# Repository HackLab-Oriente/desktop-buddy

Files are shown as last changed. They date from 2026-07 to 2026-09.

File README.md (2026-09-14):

# Desktop Buddy

Un compañero de escritorio abierto y hackeable sobre ESP32 — hecho por y para
nuestro HackLab.

## Qué es

Una criatura pequeña que vive en tu escritorio. Tiene cara, reacciona cuando
la tocas, emite sonidos y gestos, y tiene personalidad — impulsada por un LLM.
Es un **compañero primero**: la gracia, la expresividad y la personalidad son
el producto. La utilidad (recordatorios, calendario, integraciones) llega
después, como *skills* opcionales que cualquiera de la comunidad puede
construir.

Dos compromisos de diseño lo definen todo:

1. **El comportamiento es datos, no firmware.** El ESP32 ejecuta un núcleo C++
   estable (el framework). Todo lo que hace que un buddy sea *tu* buddy — su
   cara, sus estados de ánimo, sus reacciones, su voz, su system prompt — es un
   **pack de personalidad**: scripts y assets que editas desde una web y
   recargas en caliente sin recompilar. Las personalidades se comparten, se
   forkean y se intercambian — como cartuchos.

2. **Primero el dispositivo, el hub es opcional.** El buddy está completamente
   vivo por sí solo: los reflejos locales funcionan sin internet, y habla con
   un proveedor de LLM directamente por WiFi para conversar. El dispositivo
   habla con "un cerebro" a través de un protocolo pequeño — por defecto ese
   cerebro es un adaptador cloud en el propio dispositivo, pero el mismo
   endpoint puede apuntar a un servidor hub opcional para los trucos pesados
   (webhooks, integraciones, memoria a largo plazo). Sin hub no pasa nada: el
   buddy degrada con gracia, **nunca se rompe**.

## Conceptos

Dentro del framework todo es un evento en un bus, y hay cuatro primitivas de
extensión:

| Primitiva | Qué es | Ejemplos |
|---|---|---|
| **Senses** | Entradas que emiten eventos | tacto, micro, sensores, timers |
| **Expressions** | Salidas que consumen acciones | cara, sonidos, LEDs, motores |
| **Reflexes** | Comportamiento local scriptado (evento → acción), sin latencia, offline | lo acaricias → ronronea; sala a oscuras → se duerme |
| **Skills** | Capacidades mediadas por el LLM expuestas como herramientas | recordatorios, calendario (las construye la comunidad) |

Un **pack de personalidad** agrupa: system prompt, expresiones con nombre
(estado → cara/color/animación), reflejos y frases. El contrato completo está
en [docs/pack-format.md](docs/pack-format.md).

## Arranque en 5 minutos

Necesitas [ESP-IDF v6.x](https://docs.espressif.com/projects/esp-idf/en/latest/esp32/get-started/)
(la v5 **no** sirve para este proyecto) y una placa **ESP32-S3** — la N16R8 es
la de referencia. La caché de la cara y el modelo local viven en PSRAM, así
que se recomienda con firmeza. Aun sin ella el firmware arranca y dibuja, pero
la cara va a 12-25 fps en vez de 35 y el modelo local no cabe.

```bash
# --recursive importa: sin los submódulos (Berry y LovyanGFX) no compila
git clone --recursive git@github.com:HackLab-Oriente/desktop-buddy.git
cd desktop-buddy/firmware

idf.py set-target esp32s3
idf.py menuconfig           # menú "Buddy Zero": WiFi, API key (opcional)
idf.py build flash monitor
```

Guía completa, cableado y la escalera de PoCs: [firmware/README.md](firmware/README.md).

## Preparar el editor

Todo compila desde la terminal con `idf.py` — el editor es comodidad, no
requisito. Pero con el IDE bien puesto tienes autocompletado real sobre
ESP-IDF, y un botón de flash/monitor.

### VS Code, Cursor, Antigravity, Windsurf (todos son forks de VS Code)

Abre `desktop-buddy.code-workspace` y acepta las extensiones recomendadas, o
instálalas a mano:

| Extensión | ID | Para qué |
|---|---|---|
| **ESP-IDF** | `espressif.esp-idf-extension` | Build, flash, monitor, menuconfig y depuración desde el editor. Su asistente instala también el toolchain si aún no lo tienes. |
| **clangd** | `llvm-vs-code-extensions.vscode-clangd` | Autocompletado, ir-a-definición y errores en vivo, leyendo el `compile_commands.json` real del build. |
| *(opcional)* Berry | `skiars.berry` | Resaltado de los reflejos `.be`. Si no la instalas, el repo los muestra como Python, que se parece bastante. |

**No instales `ms-vscode.cpptools`** (la extensión C/C++ de Microsoft). Pelea
con clangd por las mismas funciones y da resultados peores en proyectos
ESP-IDF; además es propietaria y no está en Open VSX, así que en Cursor,
Antigravity o Windsurf directamente no se instala. El workspace la marca como
no recomendada por eso.

Dos detalles que ahorran una tarde:

- **Abre el workspace, no la carpeta suelta.** clangd necesita el
  `compile_commands.json`, que lo genera el build en `firmware/build/` — no
  en la raíz del repo. Apuntado a un sitio sin él, clangd *no falla*: adivina
  los flags y parece que funciona hasta que discrepa del compilador.
- **Compila una vez antes de esperar autocompletado.** Sin build no hay
  `compile_commands.json` que leer.

Los ajustes propios de cada máquina (ruta de ESP-IDF, puerto serie, binario
de clangd) **no van en el repo**: la extensión de ESP-IDF reescribe
`settings.json` con rutas absolutas de quien la ejecutó, así que esos
archivos están en `.gitignore`. Copia las plantillas:

```bash
cp .vscode/settings.example.json .vscode/settings.json
cp firmware/.vscode/settings.example.json firmware/.vscode/settings.json
```

### CLion (alternativa)

Funciona bien y a algunos les resulta más cómodo para C++. El proyecto es
CMake normal, así que se abre directamente — pero hay que darle el toolchain
de ESP-IDF, no el del sistema:

1. Abre la carpeta **`firmware/`** (no la raíz del repo): ahí está el
   `CMakeLists.txt` de nivel superior.
2. *Settings → Build, Execution, Deployment → Toolchains* → añade uno con el
   compilador del toolchain de Xtensa
   (`~/.espressif/tools/xtensa-esp-elf/…/bin/xtensa-esp32s3-elf-gcc`).
3. En *CMake profiles*, añade a las opciones:
   `-DCMAKE_TOOLCHAIN_FILE=$IDF_PATH/tools/cmake/toolchain-esp32s3.cmake
   -DTARGET=esp32s3`, y
   arranca CLion desde una terminal donde hayas hecho `source` del script de
   activación de ESP-IDF, para que herede `IDF_PATH`.
4. Flash y monitor siguen siendo `idf.py -p PUERTO flash monitor` en la
   terminal integrada — el plugin oficial de Espressif es solo para VS Code.

La ganancia real de CLion aquí es el indexador y el depurador; el ciclo de
flasheo se queda en la terminal en cualquier caso.

### Solo terminal

Perfectamente válido, y es como se hicieron todas las mediciones de este
repo:

```bash
source ~/.espressif/tools/activate_idf_v6.1.sh
cd firmware && idf.py build flash monitor
```

### ¿Qué placa necesito?

Un **ESP32-S3 con PSRAM**; la referencia es la N16R8 (16 MB de flash, 8 MB de
PSRAM). El ESP32 clásico estuvo soportado y funcionaba —la cara se dibujaba
por bandas a 14,4 fps— pero se retiró: sin PSRAM no hay caché de ojos ni
modelo local, y mantener dos caminos de render costaba más de lo que daba.

## ¿Dónde me meto?

Según el equipo en el que estés (o quieras estar):

- **Firmware y arquitectura** → [firmware/README.md](firmware/README.md) y
  [docs/event-registry.md](docs/event-registry.md) — el contrato entre equipos.
- **Web UI / PWA** → el servidor vive en `firmware/components/webui/`; el
  esquema de configuración, el manejo de secretos y el aprovisionamiento por
  SoftAP están propuestos en [docs/config-api.md](docs/config-api.md) — léelo
  antes de empezar.
- **Voz** → [docs/services.md](docs/services.md) y los eventos `voice.*` que
  aún no existen ([docs/event-registry.md](docs/event-registry.md), sección
  «Eventos propuestos»).
- **Electrónica** → [docs/hardware.md](docs/hardware.md) (BOM y pedidos) y
  [hardware/](hardware/) (guías de cableado por placa).
- **CAD y carcasa** → [docs/hardware.md](docs/hardware.md), sección de
  alimentación y montaje.
- **Personalidad y contenido** → [docs/pack-format.md](docs/pack-format.md) y
  [packs/](packs/) — no hace falta saber programar para escribir frases.

## Estructura del repo

```
firmware/     núcleo ESP-IDF (C++): drivers, bus de eventos, VM Berry, web
packs/        packs de personalidad (scripts + assets); packs/zero es la semilla
hardware/     guías de cableado por placa, diagramas, máscaras imprimibles
docs/         arquitectura, decisiones, talleres — índice en docs/README.md
spikes/       experimentos desechables; solo sus conclusiones van a main
```

## Documentación

### 📖 **[hacklaboriente.org/desktop-buddy](https://hacklaboriente.org/desktop-buddy/)**

Ahí está todo, con los documentos interactivos funcionando de verdad: la
reunión de equipos, el registro de eventos, el explorador de parámetros, el
laboratorio de cadenas de Markov y las dos arquitecturas.

Si solo vas a leer tres cosas: [la arquitectura](docs/architecture.md), [el
plan de talleres](docs/workshops.md) y [cómo contribuir](CONTRIBUTING.md).

> **Ojo:** los `.html` de `docs/` son páginas interactivas. Si los abres desde
> el navegador de archivos de GitHub verás el código fuente, no la página —
> usa el enlace de arriba. El índice en texto plano está en
> [docs/README.md](docs/README.md).

> Idiomas: la documentación está en español; el código y sus comentarios, en
> inglés. `CLAUDE.md` y `.kiro/` son configuración de las herramientas de IA
> del proyecto y permanecen en inglés.

## Estado

En construcción activa durante los talleres (4 sesiones, del 29 de agosto al
19 de septiembre de 2026 — ver [docs/workshops.md](docs/workshops.md)). Todo
lo que hay aquí es una propuesta — discútela. Licencia: [MIT](LICENSE).

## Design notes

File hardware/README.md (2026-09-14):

# Hardware — guías de cableado

La BOM completa, los pedidos y la arquitectura de alimentación viven en
[../docs/hardware.md](../docs/hardware.md). Aquí están las guías prácticas
por placa:

| Guía | Placa | Estado |
|---|---|---|
| [buddy-s3-display.md](buddy-s3-display.md) | **ESP32-S3 N16R8** — la de referencia | verificada en hardware |
| [buddy-zero-wiring.md](buddy-zero-wiring.md) | **ESP32 clásico** DevKit V1 | **histórica** — target retirado |
| [buddy-s3-audio.md](buddy-s3-audio.md) | **S3** — micro, ampli y tarjeta SD | **propuesta, sin firmware todavía** |

También: la máscara imprimible [`round-mask/`](round-mask/).

**Históricas**, se conservan porque documentan trabajo hecho y verificado:
[`oled-mask/`](oled-mask/), la máscara de la PoC monocroma cuyo backend ya no
existe; y el cableado del ESP32 clásico —`buddy-zero-wiring.md` más su
`buddy-zero.wireviz.yml`—, para un target que el firmware ya no compila.

Regla que lo explica casi todo: **cada chip tiene minas distintas**, y por eso
los pines viven en `menuconfig` y nunca hardcodeados. En el S3 —el único
target— GPIO 33–37 son la PSRAM, 19/20 el USB, 26–32 la flash y 0/3/45/46
strapping. En el clásico eran 6–11 flash, 12 y 15 strapping y 34–39 solo
entrada: eso ya solo hace falta para leer el cableado histórico.

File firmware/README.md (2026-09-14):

# Firmware — Buddy Zero

El núcleo del framework: bus de eventos, host de Berry, drivers de Senses y
Expressions, el adaptador de cerebro cloud y la web de recarga en caliente.

## Un target

| | `esp32s3` (referencia) |
|---|---|
| Bus, Berry, web UI, cerebro cloud, tacto, NFC | ✓ |
| Cara GC9A01 a color | ✓ frame completo + caché PSRAM, **33 fps medidos** |
| Modelo local / voz | ✓ / planificado |
| Verificado | en hardware, completo |

## La capa gráfica

Los ojos los dibuja **nuestro** renderer de campos de distancia (SDF), porque
la ceja y el guiño de felicidad se recortan de la forma como *cobertura* —
ninguna primitiva de librería expresa eso. Todo lo demás (driver del panel,
sprites, blitting) es **LovyanGFX**.

**La fuente también es nuestra**, y no por gusto: *todas* las que trae
LovyanGFX se paran en 0x7E/0x7F — `Font2` calcula literalmente
`(uniCode - 0x20) < 0x60`, 96 glifos. Es decir, `á` salía como un cuadrado.
Las únicas fuentes Unicode de la librería son las efont, y son 17–32 MB de
CJK. Así que `tools/make_font.py` genera `font_latin.h` (DejaVu Sans 13 px,
0x20–0xFF, **4 KB**) y con eso el buddy escribe español de verdad. Se
regenera a mano y se commitea; el build no lo ejecuta.

Lo que va más allá de 0x00FF —las comillas curvas y las rayas que un LLM
adora— lo pliega `latin1.h` a ASCII antes de dibujar, porque un glifo que no
existe se dibuja como nada y `don’t` perdería el apóstrofo.

En el S3 los ojos van **cacheados**: el SDF cuesta 40–100 ms por frame, pero
la imagen solo cambia al parpadear o cambiar de emoción — una sacada es una
*traslación* de una imagen que no cambió. Renderizar una vez por (emoción,
apertura) en tres sprites PSRAM y blitear con offset de mirada lo lleva de 13
a 33 fps medidos, píxel por píxel idéntico. Todo se midió primero en
[../spikes/lovyangfx-gc9a01/](../spikes/lovyangfx-gc9a01/README.md), que
registra las trampas — la principal: **LovyanGFX guarda los sprites de 16 bpp
en big-endian**; escribir little-endian nativo en `getBuffer()` convierte los
degradados en franjas arcoíris.

## El arranque

`face_start()` corre primero en `app_main`, así el splash está en pantalla
mientras lo lento pasa por detrás. La retroiluminación no se enciende hasta
después del init del panel — el arranque se lee como oscuro → estática → logo.
El logo del HackLab «sintoniza» como una tele estropeada (~1,6 s) y la línea
de estado la publican los pasos reales de `app_main` vía `boot.status`.
`boot.ready` hace glitch del splash a la cara. En un arranque típico la línea
se queda ~4 s en "connecting wifi": ese es el cuello de botella honesto.

## Setup

```bash
# 1. ESP-IDF v6.x (la v5 NO está soportada). El instalador EIM deja el script
#    de activación en ~/.espressif/tools/activate_idf_v6.1.sh — haz source.
# 2. Submódulos: Berry (VM de reflejos) y LovyanGFX (capa gráfica).
git submodule update --init
cd firmware/components/berry_host/berry
mkdir -p generate && python3 tools/coc/coc -o generate src default -c default/berry_conf.h
#    (Sin el submódulo/codegen el build compila igual, pero el buddy se queda
#     sin reflejos: el fallback en C se borró en #71 por ser una segunda copia
#     del comportamiento semilla que se desincronizaba en silencio.)

cd ../../..            # de vuelta a firmware/
idf.py set-target esp32s3    # el único target
idf.py menuconfig            # menú "Buddy Zero": WiFi, API key, pines
idf.py build flash monitor
```

`set-target` regenera `sdkconfig` desde `sdkconfig.defaults` +
`sdkconfig.defaults.esp32s3`, con la tabla de particiones de 16 MB e imagen
de modelo local.

### Build de desarrollo

`CONFIG_BUDDY_DEBUG` viene en `n`, así que un `monitor` recién clonado sale
callado: no traza los eventos del bus, ni los cuerpos HTTP del cerebro, ni las
lecturas del táctil. Está en `n` por una razón medida —el tracer bloquea el bus
15-20 ms por gesto a 115200 baudios— que solo importa en un buddy terminado.
Mientras desarrollas, pide `sdkconfig.defaults.dev`:

```bash
idf.py -DSDKCONFIG_DEFAULTS="sdkconfig.defaults;sdkconfig.defaults.esp32s3;sdkconfig.defaults.dev" set-target esp32s3
```

Los ficheros van explícitos a propósito: `-DSDKCONFIG_DEFAULTS` sustituye la
lista entera, y olvidar el del target deja el S3 sin PSRAM y por tanto sin
caché de ojos. El fichero es tuyo para crecer: lo que quieras en tu mesa y no
en el buddy de nadie más.

### Tus credenciales, y por qué no van en `sdkconfig`

`idf.py set-target` **regenera `sdkconfig` desde cero**, así que todo lo que
solo viviera ahí —tu SSID, tu contraseña, tu clave de API— desaparece. Duele
cada vez que se cambia de target o de versión de ESP-IDF.

Copia `sdkconfig.defaults.local.example` a `sdkconfig.defaults.local`, que
está gitignorado, y añádelo **al final** de la lista, que es la posición que
gana:

```bash
idf.py -DSDKCONFIG_DEFAULTS="sdkconfig.defaults;sdkconfig.defaults.esp32s3;sdkconfig.defaults.dev;sdkconfig.defaults.local" \
       set-target esp32s3
```

Con eso, regenerar es gratis: `fullclean`, `set-target`, y sigues teniendo tu
red y tu clave.

Que la clave de API viva en un fichero de build es una decisión de PoC, no el
diseño. En v1 va en NVS y se pone desde el web UI (#5). Mientras tanto, ten
presente que **el binario compilado es una credencial**: `strings
build/buddy.bin` la encuentra. No lo pases por un taller ni lo cuelgues de
una release.

## Cableado

Los pines viven en `menuconfig`, nunca hardcodeados.

| Periférico | ESP32-S3 |
|---|---|
| GC9A01 (SPI, **3V3**) | SCL 12 · SDA 11 · CS 10 · DC 9 · RST 8 · BL 7 |
| Almohadilla táctil | GPIO 4 |
| Anillo WS2812 (**5V**) | DIN 21 |
| RC522 (opcional, **3V3**) | SCK 39 · MISO 40 · MOSI 41 · SDA/CS 42 · RST 38 |

En el RC522 no hay ningún pin marcado «CS»: el módulo serigrafía **`SDA`**, que
en SPI es el chip select. El `IRQ` va sin conectar — el driver hace polling.

Guía paso a paso con checklist de primer arranque:
[../hardware/buddy-s3-display.md](../hardware/buddy-s3-display.md).

Minas del S3: 33–37 PSRAM octal, 19/20 USB, 26–32 flash, 0/3/45/46 strapping.

## La escalera de PoCs

1. **Latido** — flashea, mira el log serie, toca el jumper: `touch.pet` → el
   anillo respira. El bus funciona.
2. **Proto-cara** — la pantalla muestra dos ojos paramétricos: parpadeos,
   sacadas, emociones. Payloads de `face.emotion`: neutral, happy, curious,
   sleepy, surprised, angry, sad, suspicious.
3. **Cartuchos** — acerca un llavero RFID: `nfc.tag` + UID en el log. Pon tus
   UIDs en `packs/zero/reflexes/main.be` vía web y repite.
4. **Cerebro** — con WiFi + API key: acaricia el cable, el buddy pregunta a
   Claude y la emoción de la respuesta mueve la cara.
5. **Recarga en caliente** — abre `http://<ip-del-buddy>/`, edita reflejos en
   el navegador, sube — el comportamiento cambia sin reflashear. La tesis
   entera del framework en un botón.

## Estructura

```
components/bus/          bus de eventos (testeable en host — ver host_test/)
components/senses/       tacto, RC522 → eventos
components/expressions/  cara a color, anillo WS2812 ← acciones
components/brain/        contrato de cerebro: adaptador cloud (Claude)
components/webui/        WiFi STA + editor de reflejos + recarga en caliente
components/berry_host/   VM Berry, API buddy.*, despacho de eventos
main/                    arranque + el único reflejo del framework (brain.reply)
../packs/zero/           los reflejos Berry de Buddy Zero
```

El contrato de eventos completo (con dueños por prefijo y agujeros conocidos):
[../docs/event-registry.md](../docs/event-registry.md).

## Tests de host

```bash
cd host_test
c++ -std=c++17 -Wall -I../components/bus/include test_bus.cpp ../components/bus/bus.cpp -o test_bus
./test_bus    # se espera: "bus: all tests passed"

# El decodificador NDEF lee bytes de una pegatina que cualquiera puede dejar
# en tu mesa, así que se prueba con sanitizers puestos.
c++ -std=c++17 -Wall -fsanitize=address,undefined -fno-sanitize-recover=all \
  -I../components/senses test_ndef.cpp -o test_ndef
./test_ndef   # se espera: "ndef: all tests passed"

# El normalizador de texto recorre UTF-8 del LLM hacia un buffer fijo: mismo
# tipo de código, mismos sanitizers.
c++ -std=c++17 -Wall -fsanitize=address,undefined -fno-sanitize-recover=all \
  -I../components/expressions test_latin1.cpp -o test_latin1
./test_latin1 # se espera: "latin1: all tests passed"
```

## Estado

- **Verificado**: compila en ESP-IDF v6.1; el bus pasa sus tests de host; el
  S3 completo funciona en hardware (cara, anillo, tacto, WiFi, cerebro
  Claude). Render medido: **30,3 ms/frame (33,0 fps)**.
- **Sin cablear todavía**: audio (INMP441/MAX98357A), tarjeta SD, sensores
  I2C.

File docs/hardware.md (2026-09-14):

# Hardware: componentes y cableado (build de referencia v1)

Construimos desde cero: elegimos componentes, los cableamos, y diseñamos e
imprimimos nuestra propia carcasa. Esta es la BOM propuesta para v1 — la
elección final es decisión de grupo en la sesión 1, pero **los componentes
deben pedirse antes de la sesión 1**.

## Núcleo

| Pieza | Sugerencia | Notas |
|---|---|---|
| MCU | **Devkit ESP32-S3, N16R8** (16 MB flash / 8 MB PSRAM) | El S3 es necesario para el roadmap de voz (instrucciones vectoriales de ESP-SR); la PSRAM para gráficos + buffers de audio. Pilla el devkit con ambos puertos USB expuestos. *(El ESP32 clásico se retiró en #80: sin PSRAM no hay caché de ojos, ni modelo local, ni voz, y mantener el segundo camino de render costaba más de lo que devolvía.)* |
| Pantalla | **A elección de cada uno:** GC9A01 redonda 1,28″ o ST7789 cuadrada 1,54″ — ambas 240×240, SPI | Misma resolución, mismo cableado, mismo stack gráfico — solo cambia la secuencia de init (un flag, no un fork). Regla: las caras se crean en un canvas de 240×240 con ojos/boca dentro del círculo inscrito ("zona segura redonda"). Evita los OLED I2C clase SSD1306: monocromos, 128×64, e I2C demasiado lento para animación. Rectangulares más grandes (ST7789 2″ / ILI9341 2,4–2,8″, 320×240) son post-v1 — rompen la paridad de resolución. |
| Tacto (caricias) | Pines capacitivos **nativos del ESP32** + cinta de cobre bajo la carcasa | Gratis (sin componente), y "acariciar la carcasa" gana a "tocar la pantalla" para una criatura. Una pantalla táctil es extra opcional. |
| Micrófono | **INMP441** (MEMS I2S) | Digital, sin líos analógicos. v1 lo usa para nivel de sonido (un Sense) y streaming STT del push-to-talk; el uso de sobremesa no necesita array de micros. |
| Salida de audio | **MAX98357A** (ampli I2S) + altavoz 4Ω 3W (~28 mm) | Chirps, efectos y reproducción TTS para el bucle PTT de v1. Sin canal de loopback → sin AEC → half-duplex por diseño. |
| Extras | LED RGB WS2812 (luz de ánimo), un botón de repuesto | Barato, expresivo, buen material de relleno para talleres. |

Coste estimado por buddy: **≈ 20–30 €** en cantidades unitarias. Pide al menos
un repuesto de todo; los micros MEMS y las pantallas baratas tienen bajas.

## Lista de compra y seguimiento de pedidos

Marca los items al pedirlos. **Decisión del lab (2026-07): construir 2–3
prototipos, no uno por miembro** — el pedido actual cubre exactamente eso (3
builds con repuestos). Cuando v1 esté sólida, el camino a un producto pulido
es un **lote de PCB portadora fabricada** (ver Alimentación y montaje), no más
protoboards.

### Componentes de núcleo (verificados 2026-07-13, pedidos)

- [x] Devkit ESP32-S3 N16R8, doble USB-C, pack de 3 (Hosyond) — [B0F5QCK6X5](https://www.amazon.com/dp/B0F5QCK6X5)
- [x] Pantalla GC9A01 redonda 1,28″, 240×240 SPI, pack de 5 (D-FLIFE) — [B0DCBM8KV1](https://www.amazon.com/dp/B0DCBM8KV1)
- [x] Micrófono MEMS I2S INMP441, pack de 5 — [B0C1C64R8S](https://www.amazon.com/dp/B0C1C64R8S)
- [x] Breakout ampli I2S MAX98357A 3 W, pack de 6 — [B0FHWB5VFW](https://www.amazon.com/dp/B0FHWB5VFW)
- [x] Anillo WS2812 de 12 LED, pack de 5 — [B0C77WMM7B](https://www.amazon.com/dp/B0C77WMM7B)
  (capar el brillo en firmware: 12 LEDs a blanco pleno ≈ 700 mA a 5 V)
- [x] Altavoz 4Ω 3W ultrafino 35×25×6,8 mm, coleta JST 1.25, pack de 5 (DWEII) — [B0F3CY5ZD2](https://www.amazon.com/dp/B0F3CY5ZD2)
  (nota de montaje: cortar el JST a ras, pelar 5 mm, estañar, atornillar al terminal de salida del MAX98357A)

### Extras

- [ ] Kit de protoboards, 2×830 + 2×400 puntos + 126 jumpers (BOJACK) — [B08Y59P6D1](https://www.amazon.com/dp/B08Y59P6D1) — prototipado sesiones 1–3
- [ ] Cables Dupont 120 uds M-M/M-H/H-H (ELEGOO) — [B01EV70C78](https://www.amazon.com/dp/B01EV70C78) — los H-H conectan el módulo de pantalla directo a los pines del devkit
- [x] Cinta de cobre 2″×33 ft, adhesivo conductor (LOVIMAG) — [B07C6YLNYL](https://www.amazon.com/dp/B07C6YLNYL) — las almohadillas capacitivas
- [x] Pulsadores táctiles 6 mm, pack de 20, para protoboard — [B07WF76VHT](https://www.amazon.com/dp/B07WF76VHT) — entrada de repuesto / botón de boot
- [x] Protoboard soldable (ElectroCookie) — [B07ZYNWJ1S](https://www.amazon.com/dp/B07ZYNWJ1S) — el montaje final replica el layout de protoboard 1:1
- [x] Kit de insertos M3 + tornillos, 361 uds con puntas para soldador — [B0G8JLX1HR](https://www.amazon.com/dp/B0G8JLX1HR) — atornillar la carcasa; la vas a reabrir constantemente
- [x] Cable de silicona 22 AWG, 6 colores ×10 ft (Fermerry) — [B089CQHRDT](https://www.amazon.com/dp/B089CQHRDT) — almohadillas, tiradas de altavoz, piezas montadas en carcasa

### Hardware del hack port (por pedir)

El hack port del panel trasero necesita conectores de verdad, no solo un
recorte en la carcasa:

- [ ] Surtido de tiras de pines, macho + hembra, fila simple/doble 2,54 mm, 138 uds — [B0GLHJ3DXH](https://www.amazon.com/dp/B0GLHJ3DXH) (~$10) — el puerto en sí es un zócalo **hembra** 2×4 (compatible Dupont) pegado al recorte; el kit además cubre reparaciones de headers en todas partes
- [ ] Kit de cables Qwiic/Stemma QT, JST-SH 1,0 mm a Dupont — [B08HQ1VSVL](https://www.amazon.com/dp/B08HQ1VSVL) (~$8) — adapta el enorme ecosistema de sensores I2C Qwiic/Stemma directo al hack port, sin crimpar, sin conector SH de panel

**Mapa 2×4 propuesto** (congelar en la sesión 1):

```
3V3   SDA
5V    SCL
GND   GPIO A  (ADC + táctil)
GND   GPIO B  (ADC + táctil)
```

I2C es el bus de extensión (por direcciones, alimentado, y todo el catálogo
Qwiic entra con los cables adaptadores); los dos GPIO crudos cubren botones,
sensores analógicos o una almohadilla táctil extra. En firmware: los pines
del hack port son de la capa Berry — lectura/escritura digital/analógica y
tacto desde scripts con cero C++; los dispositivos I2C usan Senses con
driver.

### Sensores integrados v1 (por pedir)

Kit de consciencia, integrado en cada buddy (no son accesorios del hack
port). Todos alimentan el `sensor_snapshot` del Brain (consciencia
conversacional gratis) y emiten eventos del bus para los reflejos. Los
drivers/máquinas de estados los escriben agentes de IA; los costes humanos
son colocación, montaje y ajuste — anotados por sensor.

- [ ] Combo AHT20 + BMP280 temp/humedad/presión, I2C, pack de 5 — [B0G1RDY1Y8](https://www.amazon.com/dp/B0G1RDY1Y8) (~$8)
  — colocación: en la rejilla de entrada, bajo en la carcasa (el autocalentamiento del recinto lee 3–5 °C de más). La tendencia de presión = charla del tiempo.
- [ ] MPU6050 (GY-521) acelerómetro + giroscopio, I2C, pack de 5 (AITRIP) — [B07RXQGGJX](https://www.amazon.com/dp/B07RXQGGJX) (~$10)
  — montaje: rígido, atornillado o bien pegado a la carcasa (no flotando de los cables). La capa de gestos (`motion.pickup`, `motion.shake`, `motion.tilt`) la escribe la IA pero necesita play-testing humano para ajustar umbrales — presupuesta una hora divertida.
- [ ] Radar de presencia mmWave LD2410C, UART/GPIO, pack de 3 — [B0FKBF3CT4](https://www.amazon.com/dp/B0FKBF3CT4) ($19)
  — el rey de la consciencia: detecta que llegas/te sientas/te vas *a través de la carcasa de PLA* — cero agujeros. Montar mirando al frente tras la pared. Usa UART, no I2C.
- [ ] VL53L0X distancia ToF (láser), I2C, pack de 5 (Starry) — [B0DZWS6WC5](https://www.amazon.com/dp/B0DZWS6WC5) ($15) — *opcional*
  — anticipación: mano acercándose → emocionado antes del contacto. Necesita apertura real o ventana transparente (el láser IR no atraviesa el PLA).

~$58 en total, cubre 3 builds con repuestos. Todos los sensores I2C comparten
el único bus (un par `Wire`, direcciones distintas — sin coste de pines por
sensor). Descartados por ahora: calidad de aire clase ENS160 (necesita
rodaje, deriva — buen experimento de lab más adelante), PIR (instrumento
romo; el radar lo supera en todo).

### Alimentación, prep de servos y NFC (por pedir)

Piezas de la arquitectura de alimentación (ver *Alimentación y montaje*) más
las dos adiciones aprobadas con vistas al futuro:

- [ ] Extensión USB-C de panel, macho→hembra, montaje a tornillo, pack de 2 — [B0G43JGJRX](https://www.amazon.com/dp/B0G43JGJRX) ($10; **pedir ×2** para 3 builds + repuesto)
  — la entrada de energía de la carcasa; alimenta el raíl de 5 V directo, el USB del devkit queda solo para depurar
- [ ] Micro servos MG90S de engranaje metálico, pack de 6 — [B0DRHX1L5Q](https://www.amazon.com/dp/B0DRHX1L5Q) ($18)
  — 2 por buddy para el cuello pan/tilt de v2; el prototipado en banco puede empezar justo tras la sesión 4. v1 solo *reserva* sus pines y margen de potencia
- [ ] Módulo lector NFC PN532 (modo I2C), pack de 3 — [B0DTHPL3GG](https://www.amazon.com/dp/B0DTHPL3GG) ($19)
  — un dispositivo más en el bus I2C compartido; lee a través de la carcasa de PLA, cero agujeros. Stretch de la sesión 4: tap a un tag para cambiar de personalidad
- [x] Pegatinas NFC NTAG215, pack de 50 — [B0CHVWTRGC](https://www.amazon.com/dp/B0CHVWTRGC) ($13)
  — cartuchos de pack, tokens de modo, tótems impresos. Regla: los tags disparan solo acciones de lista blanca — nunca auth, nunca entrada cruda al Brain
- [x] Módulo micro SD, SPI 3,3 V (sin conversor de nivel), pack de 6 (WWZMDiB) — [B0BV8ZQ81F](https://www.amazon.com/dp/B0BV8ZQ81F) ($7)
  — almacenamiento de media para packs de contenido (voz pre-generada, imágenes, sonidos — ej. el explicador de juegos de mesa). Comparte el bus SPI de la pantalla con su propio CS; montado solo-lectura en operación normal, escrituras solo en subidas desde la web. Evita las variantes con "conversor lógico 3.3V/5V" — el conversor causa los fallos clásicos de SD-en-ESP32

### Confirmar que alguien ya tiene (no pedir a ciegas)

- [ ] Soldador + estaño + flux (el soldador también instala los insertos)
- [ ] Pelacables, alicates de corte a ras
- [ ] Pistola de silicona caliente
- [ ] Multímetro
- [ ] Cables USB-C **de datos** (los de solo-carga son el clásico sumidero de tiempo en talleres)
- [ ] **Cargadores de pared USB-C, 15 W+ (5 V/3 A)** — uno por buddy; cualquier cargador de móvil moderno vale
- [ ] Tarjetas micro SD, 8–32 GB (clase A1 vale) — una por buddy; hay en cualquier cajón
- [ ] Polyfuse ~500 mA (protección del hack port) + condensadores electrolíticos de 1000 µF (raíl de 5 V) — piezas clásicas de cajón de lab
- [ ] Filamento PLA/PETG para la carcasa

## Alimentación y montaje

**Regla de arquitectura: las cargas nunca pasan por el devkit.** El consumo
pico de v1 es ~1,1–1,5 A a 5 V (ráfagas WiFi + altavoz + anillo capado +
radar), que excede el conector USB y las pistas de 5 V del devkit — la fuente
clásica de fantasmas tipo "se reinicia cuando suena el altavoz".

- **Entrada de energía**: USB-C de panel en la carcasa → **raíl de
  distribución de 5 V** en la protoboard (topología en estrella) con un
  electrolítico de 1000 µF. Devkit, ampli, anillo, radar y hack port beben
  todos del raíl. El USB del devkit queda solo para programar/depurar.
- **Fuente**: cargador USB-C de 5 V/3 A (15 W+) por buddy. El margen ya cubre
  los servos de v2 (~1–1,5 A de picos de bloqueo) sin rehacer nada.
- **El 5 V del hack port** pasa por un polyfuse de ~500 mA — un accesorio en
  corto apaga el experimento, no el buddy.
- **Gobernador de potencia en firmware**: cap de brillo del LED, volumen
  máximo del altavoz y (después) los movimientos de servo se coordinan en la
  capa Expression para que los peores casos no se apilen. ~20 líneas;
  política, no conocimiento tribal.
- **La batería = el módulo "base de potencia" de v2, no la cabeza.** Una
  18650 + placa de carga/boost (clase IP5306: carga, boost a 5 V y load
  sharing en un chip) vive en la misma base atornillable que el cuello servo:
  la masa de la batería hace de lastre para la cabeza móvil, el calor queda
  lejos del sensor de temperatura, y la base alimenta la cabeza por la
  costura USB-C existente — la cabeza no distingue pared, power bank o
  batería. Hack de portabilidad v1.5: cualquier power bank USB-C (el consumo
  en reposo de ~200 mA queda por encima del umbral de autoapagado de los
  power banks baratos).
- Protoboard para las sesiones 1–2; pasar a protoboard soldada o PCB
  portadora simple para el montaje final en la sesión 4. Una PCB portadora
  diseñada en paralelo por quien le interese es un side-track estupendo pero
  no puede bloquear el montaje.

## Carcasa

- Impresa en 3D, carcasa de dos piezas alrededor de la pantalla ("cabeza")
  con rejilla de altavoz, agujero de micro y una **entrada USB-C de panel**
  (desacoplada del puerto del devkit — se acabó alinear recortes con una
  placa). Almohadillas capacitivas pegadas por dentro donde la acariciarías
  naturalmente (encima de la cabeza).
- **Base preparada para cuello**: interfaz inferior plana con torres de
  tornillo M3 y canal de cables, para que la base de potencia v2 (servos +
  batería) se atornille sin reimprimir la cabeza.
- **Zona de tap NFC**: el PN532 se monta tras la carcasa (lee a través de
  2–3 mm de PLA); imprime un pequeño icono de tap en la superficie. El radar
  igualmente ve a través de la carcasa — montarlo mirando al frente.
- El diseño de la carcasa empieza en la sesión 1 (medir componentes reales),
  primera impresión de prueba en la sesión 2, impresión final entre las
  sesiones 3 y 4.

## Presupuesto de pines (comprobación, ESP32-S3)

Pantalla SPI (5–6 pines), micro I2S (3), ampli I2S (3), almohadillas táctiles
(2–4), LED (1), botón (1), bus I2C (2 — compartido por todos los sensores
integrados *y* el hack port), UART del radar (2) — cómodamente dentro del
número de GPIO del S3, dejando de sobra GPIO libres sacados a un conector en
la carcasa (el "hack port") para sensores de miembros y actuadores futuros.
Sacar GPIO sin usar + 3V3/GND a un conector externo es parte del diseño v1 de
la carcasa a propósito: es la promesa de extensibilidad hecha física.

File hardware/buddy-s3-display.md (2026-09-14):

# El buddy en ESP32-S3 — primer arranque: la cara redonda

Meta de este paso: la pantalla redonda GC9A01 mostrando la cara a color en el
ESP32-S3 (N16R8). No hace falta cablear nada más todavía — tacto, audio y
RC522 vienen deshabilitados por defecto en esta config.

## Cableado — GC9A01 (SPI) → ESP32-S3

Coincide con los defaults del firmware en `firmware/main/Kconfig.projbuild`.
Cablea por las **etiquetas de la serigrafía de la pantalla**, no por el orden
de los pines.

| Pin GC9A01 | ESP32-S3 | Notas |
|---|---|---|
| VCC | 3V3 | nunca 5 V |
| GND | GND | |
| SCL | GPIO 12 | reloj SPI (SCLK) |
| SDA | GPIO 11 | datos SPI (MOSI) |
| RES | GPIO 8 | reset |
| DC | GPIO 9 | dato/comando |
| CS | GPIO 10 | chip select |
| BLK | GPIO 7 | retroiluminación (o a 3V3 y BL = -1) |

**Minas de pines del ESP32-S3 N16R8** (la razón de esta elección):
- **GPIO 33–37 son la PSRAM octal** — no los uses jamás.
- GPIO 19/20 son USB, 0/3/45/46 son strapping, 26–32 son la flash.
- GPIO 7–12 (los elegidos) están todos libres.

## Flashearlo

```bash
cd firmware
idf.py set-target esp32s3      # primera vez en el S3 — regenera la config
idf.py menuconfig              # Buddy Zero → WiFi + clave de Anthropic (opcional)
idf.py build flash monitor
```

El ESP32-S3 + GC9A01 es el único target. El ESP32 clásico estuvo soportado y
se retiró; su cableado se conserva como registro en
[buddy-zero-wiring.md](buddy-zero-wiring.md).

## Checklist de primer arranque (idf.py monitor)

1. `face` / `buddy zero is alive` en el log, sin abortos de
   `ESP_ERROR_CHECK`.
2. Estas dos líneas **son normales**, aunque una salga en rojo:

   ```
   E spi: spi_bus_initialize(897): SPI bus already initialized.
   W LGFX: Failed to spi_bus_initialize.
   ```

   El firmware reclama el bus SPI antes que LovyanGFX a propósito, y esas dos
   líneas son el relevo. Están explicadas en `claim_bus()`, en
   `firmware/components/expressions/lgfx_buddy.h`.
3. La pantalla redonda muestra dos ojos cian sobre negro que **parpadean y
   derivan**.
4. Si la pantalla está en negro: revisa el cableado de RES/DC/CS y el 3V3.
5. Si los colores salen invertidos o mal (ej. ojos magenta): es un clon del
   GC9A01 con otro orden — invierte `cfg.invert` y/o `cfg.rgb_order` en
   `firmware/components/expressions/lgfx_buddy.h`. Los clones varían.

## Trampas que ya pisamos (para que no pierdas una tarde)

Todas están arregladas en el firmware; se documentan porque el siguiente
miembro del lab que cablee un S3 se topará con las mismas.

- **La placa reiniciaba en bucle antes de pintar un pixel, en ESP-IDF 6.1.**
  El log decía `gdma_config_transfer(425): invalid max_data_burst_size:
  4294967295` y moría en `spicommon_dma_chan_free`. LovyanGFX rellena su
  `spi_bus_config_t` con 0xFF y solo reescribe los campos que conoce; todo lo
  que deja a -1 son pines, donde -1 es justo lo correcto, así que la cosa
  funcionó durante años. La 6.1 metió `dma_burst_size` en esa struct, que no
  es un pin. Arreglo: reclamamos el bus nosotros antes, con una config de
  verdad inicializada a cero (`claim_bus()` en
  `firmware/components/expressions/lgfx_buddy.h`). En 6.0.2 no pasaba porque
  el campo no existía.

- **Stack overflow en la tarea `main` al arrancar.** `app_main` levanta la
  pantalla, el primer dibujado y la VM Berry en una sola tarea; el stack de
  3584 bytes por defecto se desborda (el pánico apunta a
  `vApplicationStackOverflowHook`). Arreglo:
  `CONFIG_ESP_MAIN_TASK_STACK_SIZE=8192` (en `sdkconfig.defaults`). La tarea
  de la cara a color corre además con 6144.
- **El tacto lee al revés en el S3.** En el ESP32 clásico un toque *baja* la
  lectura de capacitancia; en el **S3 la sube** — polaridad opuesta. El
  driver ramifica por versión de hardware (dispara por encima de la línea
  base en el S3, por debajo en el clásico). Si el tacto nunca dispara, mira
  la línea de debug `raw=… baseline=…`: tocar debería empujar `raw` ~30% por
  *encima* de la base en el S3.
- **Mismatch de Python `python` vs `python3`.** Si un build de CLI se queja
  de que el entorno "is not consistent" / "configured with python3", es que
  VS Code y una shell activada a mano eligieron symlinks de Python
  distintos. Ejecuta `idf.py fullclean` una vez desde el entorno que vayas a
  usar, y recompila.

## Anillo LED WS2812 (halo de ánimo)

El anillo de 12 LED brilla con el **color de ánimo de la emoción** (la misma
tabla que los ojos — cian neutral, rojo enfadado, azul triste…) y se anima
con `led.mood`: respirar (calm/excited), un cometa girando (thinking), o
apagado.

| Pin del anillo | ESP32-S3 | Notas |
|---|---|---|
| VCC / 5V / VDD | **5V** (VBUS) | 12 LEDs quieren 5 V; a 3V3 se ve tenue y falla |
| GND | GND | compartido con el S3 — obligatorio |
| DIN / IN | GPIO **21** | datos; **usa el lado DIN**, no DOUT |

Notas:
- **Datos a 3,3 V hacia una tira de 5 V suele funcionar** a esta longitud
  tan corta. Si el primer LED va raro o con colores mal, añade un conversor
  de nivel, o baja el VCC del anillo a ~4,3 V (un diodo en serie) para bajar
  su umbral lógico.
- **El brillo está capado en firmware** (`kMaxBright = 0.35` en
  `led_ring.cpp`). 12 LEDs a blanco pleno piden ~700 mA — más de lo que le
  gusta al pin de 5 V del devkit. Mantén el cap salvo que el anillo tenga su
  propia fuente de 5 V (el raíl de la v1).
- Config: `menuconfig → Buddy Zero → WS2812 mood ring`, pin
  `BUDDY_WS2812_PIN` (21), cantidad `BUDDY_WS2812_COUNT` (12).
- Comprobación al arrancar: `ring: WS2812 ring: 12 LEDs on GPIO 21`, y luego
  una respiración cian suave. Colores mal (ej. rojo/azul intercambiados) →
  la tira no es GRB; cambia `LED_STRIP_COLOR_COMPONENT_FMT_GRB` a `_RGB` en
  `led_ring.cpp`.

## Qué se conecta después (las piezas ya están)

Mismo S3, incremental — cada una es un Sense/Expression más en el bus:
- **Almohadilla de caricias** — el tacto funciona en el S3 (GPIO 1–14).
  Configura `BUDDY_PIN_TOUCH`.
- **Micro (INMP441) + ampli (MAX98357A) + altavoz** — la ruta de audio I2S
  (chirps primero, luego el bucle de voz push-to-talk).
- **Botones** — Senses digitales extra.

## Lector NFC RC522 (verificado en el S3)

Su propio bus SPI3, así que no comparte con la pantalla. Estos son los
defaults de menuconfig; los valores viejos del ESP32 clásico eran
directamente peligrosos en este chip porque GPIO 19/20 son el USB.

| Pin RC522 | ESP32-S3 | Notas |
|---|---|---|
| 3.3V | **3V3** | 5 V mata el módulo |
| GND | GND | |
| SCK | GPIO **39** | |
| MISO | GPIO **40** | |
| MOSI | GPIO **41** | |
| SDA / CS | GPIO **42** | el módulo lo serigrafía **SDA**; en SPI es el chip select |
| RST | GPIO **38** | |
| IRQ | — **sin conectar** | el driver hace polling; no usa la interrupción |

Si buscas un pin marcado «CS» en el módulo, no lo hay: el MFRC522 multiplexa
SPI, I2C y UART sobre los mismos pines físicos y la serigrafía usa el nombre de
I2C. **`SDA` es el chip select.** Y el `IRQ` se queda al aire a propósito:
`rc522.cpp` lee `ComIrqReg` por SPI en vez de cablear la interrupción, así que
sobra un cable y un GPIO.

Se habilita en `menuconfig → Buddy Zero → Enable RC522 RFID reader`; los
pines son configurables en el submenú. Elegidos evitando cada mina del S3:
el bus de la pantalla (7–12), USB (19/20), flash (26–32), PSRAM octal
(33–37), strapping (0/3/45/46), tacto (4) y el anillo LED (21).

Comprobación al arrancar: acerca un llavero y busca `nfc.tag` con un UID hex
en la traza.

> **Verificado en hardware** (S3, primer intento): `rc522: MFRC522 version 0x92`
> y un llavero dispara `nfc.tag` con su UID, que la cara muestra en pantalla.
> Estos pines y este cableado son reales, no una propuesta leída del datasheet.
> El **ESP32 clásico se retiró** en #80; su cableado queda como histórico.

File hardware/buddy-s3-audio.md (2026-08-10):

# Audio (INMP441 + MAX98357A) y tarjeta SD — ESP32-S3

> **PROPUESTA, sin verificar.** No hay firmware todavía: ni driver I2S, ni
> driver de SD, ni entradas en `Kconfig.projbuild`. Estos pines están elegidos
> esquivando las minas del S3 y las asignaciones que ya existen, pero **nadie
> ha encendido esto aún**. El RC522 nos acaba de recordar por qué eso importa:
> el módulo no tenía el pin que la tabla decía. Trata este documento como un
> plan de cableado, y cámbialo en cuanto la placa diga otra cosa.
>
> El primer arranque real es la [#10](https://github.com/HackLab-Oriente/desktop-buddy/issues/10)
> (grabar 3 s y reproducirlos), que es el listón de la sesión 1 para voz.

## La decisión que ahorra seis pines

Dos decisiones de arquitectura antes de la tabla, porque explican casi todos
los números que hay en ella.

**1. Un solo bus I2S, compartido entre micro y altavoz.** El INMP441 y el
MAX98357A podrían tener cada uno su reloj, pero el diseño del buddy es
**half-duplex a propósito**: nunca escucha mientras habla (si no, se oye a sí
mismo). Como jamás van a transmitir a la vez, pueden compartir `BCLK` y `WS`
y quedarse cada uno con su línea de datos. **4 pines en vez de 6**, y el
firmware usa un único puerto I2S en modo full-duplex.

**2. La SD comparte el bus SPI del RC522.** Esto no es ahorro, es obligación:
el ESP32-S3 solo tiene **dos** controladores SPI de propósito general (SPI2 y
SPI3 — SPI1 es la flash), y ya están cogidos, la pantalla en SPI2 y el RC522
en SPI3. La tercera tarjeta tiene que compartir con alguien.

Comparte con el **RC522**, no con la pantalla. La pantalla se reescribe 30
veces por segundo y LovyanGFX es dueña de ese bus; meter ahí una SD es pelearse
por el bus en cada frame. El RC522 se consulta de vez en cuando y tolera
compartir sin despeinarse. Comparten `SCK`/`MISO`/`MOSI` y cada uno tiene su
propio `CS` — que es exactamente para lo que existe el chip select.

## Los pines

| Señal | GPIO | Va a |
|---|---|---|
| I2S `BCLK` | **15** | INMP441 `SCK` **y** MAX98357A `BCLK` |
| I2S `WS` / `LRCL` | **16** | INMP441 `WS` **y** MAX98357A `LRC` |
| I2S datos de entrada | **17** | INMP441 `SD` (el micro habla) |
| I2S datos de salida | **18** | MAX98357A `DIN` (el buddy habla) |
| Mute del ampli | **2** | MAX98357A `SD` — ver abajo, no es solo apagado |
| SD `CS` | **14** | módulo SD `CS` |
| SD `SCK` / `MISO` / `MOSI` | **39 / 40 / 41** | compartidos con el RC522 |

Quedan libres **1, 5, 6, 13, 47, 48** para sensores I2C, botones y el puerto
de hackeo.

## Micro INMP441

| Pin | A | Nota |
|---|---|---|
| VDD | **3V3** | |
| GND | GND | |
| SCK | GPIO **15** | |
| WS | GPIO **16** | |
| SD | GPIO **17** | salida del micro → entrada del ESP |
| L/R | **GND** | canal izquierdo; **no lo dejes al aire** |

`L/R` al aire es la causa nº 1 de «grabo y solo hay silencio»: sin él, el
micro no sabe en qué mitad de la trama hablar y el ESP lee el hueco vacío.

## Amplificador MAX98357A

| Pin | A | Nota |
|---|---|---|
| Vin | **5V** | funciona a 3V3, pero suena bastante más flojo |
| GND | GND | |
| BCLK | GPIO **15** | compartido con el micro |
| LRC | GPIO **16** | compartido con el micro |
| DIN | GPIO **18** | |
| SD | GPIO **2** | mute por firmware — ver abajo |
| GAIN | al aire | 9 dB por defecto; suficiente para empezar |
| + / − | altavoz | **lee la sección siguiente antes de cablear esto** |

### El pin `SD` no es solo un apagado

Se llama *shutdown*, pero el nivel de tensión selecciona además el canal
(izquierdo, derecho o la media de ambos). Lo interesante para nosotros es el
extremo: **llevarlo a nivel bajo silencia el ampli de verdad**, en hardware.

Ese es exactamente el mecanismo half-duplex que la sesión 1 pide demostrar:
mientras el micro graba, el firmware baja este pin y el altavoz queda mudo de
forma física, no «bajando el volumen». Por eso gasta un GPIO en vez de dejarse
al aire.

### El altavoz: **no cortes el conector**

La salida del MAX98357A es un **puente (BTL)**: los dos terminales del altavoz
están activamente excitados, ninguno es masa.

> ⚠️ **Nunca conectes uno de los cables del altavoz a GND.** En un ampli normal
> el negativo es masa; aquí no. Poner a masa un lado del puente es cortocircuitar
> media etapa de salida, y el chip lo paga.

Con eso claro: **no hace falta cortar nada.** Ese conector de plástico es casi
seguro un **JST-PH de 2 mm** (el paso estándar de los altavoces pequeños).

1. **Lo mejor** — un latiguillo JST-PH hembra con cables sueltos (se vende en
   bolsas de diez por muy poco). El altavoz se enchufa como venía, y los dos
   cables pelados van al ampli. Reversible, y puedes cambiar de altavoz sin
   volver a soldar.
2. **Si el ampli trae bornes de tornillo**: pelas 5 mm de los cables del
   latiguillo y los aprietas. Cero soldadura.
3. **Si el ampli trae pads para soldar**: sueldas ahí los cables del
   latiguillo, y el conector sigue siendo el punto de desconexión.

Cortar el conector funciona, pero es irreversible, y en un taller donde varias
personas van a probar altavoces distintos, el conector es justo lo que quieres
conservar. Guarda el corte para cuando ya sepas qué altavoz es el definitivo.

La **polaridad no importa** con un solo altavoz: al revés solo invierte la
fase, y no hay con qué compararla. Empezará a importar el día que haya dos.

## Lector de tarjeta SD

| Pin | A | Nota |
|---|---|---|
| VCC | **depende del módulo** — ver abajo | |
| GND | GND | |
| SCK | GPIO **39** | compartido con el RC522 |
| MISO | GPIO **40** | compartido |
| MOSI | GPIO **41** | compartido |
| CS | GPIO **14** | suyo propio, no compartido |

**El detalle del VCC.** El módulo azul clásico de microSD lleva un regulador
de 3,3 V y un buffer de nivel, y está pensado para alimentarse a **5 V** con
lógica de 3,3 V — dale 3V3 al VCC y muchos funcionan a ratos, que es peor que
no funcionar. Si en cambio es una placa pequeña sin regulador (solo el
portatarjetas y unas resistencias), es de **3V3 directo** y 5 V la mata. Mira
si tiene un chip de tres patas junto al pin de VCC: si lo tiene, 5 V.

Y una advertencia de bus: **si la SD se porta mal, sospecha del reparto antes
que del módulo.** Es lo primero que hemos colgado del mismo bus que otra cosa,
y las tarjetas SD son quisquillosas con la señal — cables cortos, y si hay que
elegir quién se queda con SPI3 en exclusiva, la SD tiene más derecho que el
RC522.

## Qué falta para que esto sea real

1. Entradas en `firmware/main/Kconfig.projbuild` para estos pines (hoy no
   existen: se cambiarían recompilando, que va contra las reglas de la casa).
2. Un firmware de prueba aislado por subsistema, como pide el plan de la
   sesión 1 — no meterlo en la app principal, donde un fallo es ambiguo.
3. Los eventos `voice.*`, que tampoco existen todavía
   ([#9](https://github.com/HackLab-Oriente/desktop-buddy/issues/9)).

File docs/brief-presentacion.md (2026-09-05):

# Brief para presentación: Desktop Buddy (proyecto HackLab)

> **Instrucciones para el agente que genere la presentación:** audiencia =
> miembros del HackLab (técnicos, makers, niveles mixtos) en una reunión de
> planeación/ideación. Tono: entusiasta pero honesto, hacker-friendly, sin
> humo corporativo. Idioma: español. Duración objetivo: 15–20 min + discusión.
> Sugerencia: 12–14 slides (estructura propuesta al final). Las decisiones
> marcadas como **abiertas** deben presentarse como preguntas al equipo, no
> como hechos. Cifras y detalles técnicos: usar los de este documento, no
> inventar.

---

## 1. La idea en una frase

Una criatura de escritorio abierta y hackeable: tiene cara, reacciona cuando
la acaricias, chirrea y gesticula, conversa con personalidad propia (LLM), y
todo lo que la hace única es **data compartible, no firmware** — construida
desde cero por el HackLab (electrónica + carcasa impresa + framework propio).

**Identidad: compañero primero.** La gracia (reaccionar, gesticular,
conversar) es el producto. La utilidad tipo asistente (recordatorios,
calendario) es superficie de extensión para la comunidad, no fundación.

## 2. Inspiración / estado del arte

| Proyecto | Qué es | Qué tomamos |
|---|---|---|
| **Stack-chan / M5StackChan** (open source, ESP32-S3) | Robot kawaii de escritorio, enorme comunidad japonesa; M5Stack vende kit oficial con servos, touch, NFC | Validación total del concepto; su librería de cara (m5stack-avatar, MIT): parpadeo, sacadas, **lip-sync por amplitud**; geometría del cuello con servos |
| **Anki Vector / wire-pod** | Robot companion comercial revivido por la comunidad tras morir su nube | La lección: si depende de una nube ajena, muere con ella |
| **EMO, Eilik** | Companions comerciales cerrados | Referencia de encanto/expresividad; anti-referencia de apertura |
| **Tasmota** | Firmware ESP con scripting Berry embebido | El patrón exacto de nuestro layer de comportamiento hot-reload |
| **ESPHome / HA Voice PE** | Firmware config-driven; pipeline de voz abierto en ESP32-S3 | UX de provisioning web; referencia de voz y wake word (microWakeWord) |

**Nuestro diferencial (el pitch):** *"Stack-chan sin casero."* M5StackChan se
configura con app del fabricante + cuenta + nube XiaoZhi. El nuestro: web UI
servida por el propio dispositivo, sin cuentas, tus propias API keys,
proveedor de IA intercambiable, y reflejos que funcionan offline. Regla de
oro: **nunca brick** — sin red sigue vivo, sin nube sigue siendo tuyo.

## 3. Conceptos clave del framework

- **El comportamiento es data:** core estable en C++ (ESP-IDF) que casi nadie
  toca + scripts Berry hot-reload desde la web UI. Recompilar para cambiar
  comportamiento se considera un bug.
- **Todo es un evento** en un bus, con 4 primitivas: **Senses** (entradas),
  **Expressions** (salidas), **Reflexes** (scripts locales evento→acción),
  **Skills** (herramientas LLM, v2+).
- **Packs de personalidad = cartuchos:** prompt + caras + chirridos + reflejos
  en un zip. Compartibles, forkeables, intercambiables entre buddies.
- **Brain contract:** el firmware nunca habla con "OpenAI" o "Anthropic";
  habla con "un cerebro" (contrato único). Implementaciones intercambiables:
  adaptador cloud en el dispositivo (default v1), hub opcional (v2, para
  webhooks/integraciones), o ninguno (offline, solo reflejos).
- **Soberanía:** claves en NVS vía web UI, nunca en packs.

## 4. Hardware v1 (ya pedido para 3 builds de prueba)

- ESP32-S3 N16R8 · pantalla redonda GC9A01 240×240 (o cuadrada ST7789, misma
  resolución) · mic I2S INMP441 · amp MAX98357A + parlante plano · anillo 12×
  WS2812 como halo difuso tras el bisel · pads capacitivos de cobre bajo la
  carcasa ("acariciar", no tocar pantalla) · botón.
- **Kit de consciencia (sensores integrados):** temp/humedad/presión
  (AHT20+BMP280), IMU (MPU6050: `motion.pickup`, `motion.shake`),
  **radar de presencia mmWave LD2410C** (te detecta llegar/sentarte/irte *a
  través del plástico*, cero agujeros), ToF opcional (mano acercándose).
  Todos alimentan el `sensor_snapshot` del Brain → consciencia conversacional
  gratis ("está oscuro y la presión cae, ¿lluvia?").
- **NFC PN532** tras la carcasa + stickers NTAG215: tocar una tarjeta = cambiar
  de personalidad (el cartucho hecho físico). Solo acciones whitelisted, nunca
  auth.
- **Arquitectura de poder:** USB-C panel-mount en la carcasa → riel 5 V/3 A en
  estrella (las cargas nunca pasan por el devkit) + polyfuse en el hack port.
- **Hack port** trasero 2×4 (I2C + 2 GPIO): la promesa de extensibilidad hecha
  física; adaptadores Qwiic/Stemma QT → ecosistema completo de sensores plug &
  play.
- **Costo:** ~€60–70 por buddy con todos los sensores (~€25 el core mínimo).

## 5. Voz: push-to-talk en v1, wake word en v2

- Realidad técnica: STT de vocabulario abierto **no puede** correr en un
  ESP32-S3 (~100× la memoria/cómputo disponible). El dispositivo captura y
  transmite; el reconocimiento es cloud.
- **PTT borra los dos problemas más duros:** mantener presionado = micrófono
  activo con audio propio silenciado (half-duplex, sin cancelación de eco);
  soltar = fin de la frase (sin VAD). Un POST HTTPS del clip completo, sin
  streaming.
- Proveedores recomendados (intercambiables): Claude Haiku 4.5 (cerebro),
  OpenAI mini-transcribe (STT) y mini-tts (TTS). **~medio centavo de
  dólar por interacción de voz** (~$7/mes con uso intenso). Preset alternativo
  de una sola cuenta (todo OpenAI).
- Latencia real 1.5–3 s: no se elimina, se **enmascara** (cara de "pensando" +
  chirrido instantáneo al soltar — vive en el pack, no en el firmware).
- Wake word ("¡Hey Buddy!") = v2 con microWakeWord (entrenable por nosotros).

## 6. Roadmap

- **M0 — Está vivo:** cara animada, reacciona al tacto, WiFi + web UI básica.
- **M1 — Es hackeable:** bus de eventos + reflejos Berry hot-reload.
- **M2 — Tiene alma:** Brain contract + chat por web UI, emociones LLM, packs.
- **M3 — Escucha:** loop de voz push-to-talk completo.
- **M4 — Es tuyo:** ensamblado en carcasa propia, pack default pulido, demo.
- **v2+ (post-talleres):** wake word · **power base** (módulo atornillable:
  batería 18650 + cuello con 2 servos MG90S — el peso de la batería es lastre
  para la cabeza móvil) · cartuchos NFC · hub opcional (webhooks, calendario,
  integraciones) · más formatos de carcasa (¡Macintosh 1984 con pantalla
  cuadrada ya es viable en v1 como variante!).

## 7. Plan: 4 talleres × 4 h (+ trabajo continuo después)

Tres tracks paralelos para que nadie mire: **core** (firmware), **voz** (1–2
personas fijas), **carcasa** (CAD/impresión). Cada sesión termina con algo que
funciona: S1 definición + bring-up por subsistema · S2 cara+bus+web UI + spike
de voz · S3 personalidad + loop PTT en banco · S4 ensamblaje + demo + retro.
Pre-trabajo crítico: componentes pedidos ✅, toolchain ESP-IDF instalado antes,
API keys probadas desde laptop.

## 8. Pros y contras de meter tanto en v1 (discusión honesta)

**A favor de la ambición:**
- El bus I2C hace que cada sensor extra cueste 4 cables y ~horas de código —
  y **los agentes de IA escriben los drivers**; el costo humano real es
  colocación física y tuning, no código.
- El `sensor_snapshot` convierte sensores en encanto conversacional sin
  escribir comportamientos (el LLM reacciona solo).
- Radar y NFC leen a través del plástico: cero costo de carcasa.
- Todo el hardware ya está pedido y es barato; el riel de 5 V ya tiene margen
  para los servos de v2.

**En contra (los riesgos reales):**
- Las 4 sesiones son fijas; cada subsistema extra compite por el mismo tiempo
  de debugging. La voz ya es el ítem más arriesgado del v1.
- ~50 conexiones de cableado: intermedio, no trivial (mitigado: cada
  subsistema se prueba aislado y en paralelo).
- Riesgo cultural: el scope creep es el único riesgo capaz de matar el
  proyecto entero.

**Mitigaciones ya diseñadas (mostrar como decisiones, no esperanzas):**
- La columna de sensores es **opcional al ensamblar**: un buddy solo con cara,
  voz, tacto y halo está completo; los sensores se sueldan después sin
  reabrir nada.
- Fallback por hito: si la voz no está al final de S3, la demo corre con
  chirridos + chat web (primera clase, no plan B vergonzoso).
- Servos: v1 es *servo-ready* (base atornillable + pines reservados + margen
  de poder), no *servo-equipped*.
- Regla de specs: solo se especifica formalmente lo que dos tracks comparten
  (Brain contract, bus, formato de pack, API web).

## 9. Decisiones abiertas para el equipo (presentar como preguntas)

1. ¿Construimos un **hub mínimo** durante los talleres? (Es el track perfecto
   para los web devs; ~200 líneas; pero hay que proteger la promesa
   device-first.)
2. **Nombre** del proyecto y de la criatura.
3. Pantalla redonda vs cuadrada (misma resolución; elección por miembro).
4. ¿Cuántos buddies / quiénes construyen? (Define el segundo pedido de
   componentes.)
5. Berry vs Lua para scripting (se decide por fricción en S2 — solo informar).

## 10. Estructura de slides sugerida

1. Portada: la criatura + una frase.
2. ¿Qué es? (identidad: compañero primero, demo mental de 30 segundos).
3. Inspiración: fotos de Stack-chan, Vector, EMO — "esto existe y encanta".
4. El diferencial: "Stack-chan sin casero" (soberanía, nunca brick).
5. Cómo funciona: las 4 primitivas + packs como cartuchos (diagrama).
6. El cuerpo: hardware v1 + costo (~€60–70).
7. La consciencia: sensores + radar + NFC (los trucos "a través del plástico").
8. La voz: por qué PTT primero (y medio centavo por conversación).
9. Roadmap M0→M4 → v2+ (power base con servos como zanahoria).
10. Los 4 talleres: tracks paralelos, cada sesión termina con demo.
11. Pros/contras del scope v1 + mitigaciones.
12. Decisiones que tomamos HOY (las 5 preguntas abiertas).
13. Cierre: qué se lleva cada miembro (su propio buddy + un framework para
    hackear años).

---
_Fuente de verdad técnica: `docs/architecture.md`, `docs/hardware.md`,
`docs/services.md`, `docs/workshops.md` (en inglés). Generado 2026-07-15._

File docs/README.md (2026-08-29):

# Documentación — índice

**Publicado en → [hacklaboriente.org/desktop-buddy](https://hacklaboriente.org/desktop-buddy/)**

Los `.html` son interactivos y autocontenidos: funcionan en la web publicada y
también abriéndolos desde el disco sin internet. Lo que **no** funciona es
verlos desde el navegador de archivos de GitHub — ahí sale el código fuente.
Los `.md` se leen bien en GitHub.

## Para empezar

| Doc | Qué cuenta |
|---|---|
| [../README.md](../README.md) | Qué es el buddy y arranque en 5 minutos |
| [../CONTRIBUTING.md](../CONTRIBUTING.md) | Ramas, spikes, commits, idiomas, reglas del bus |
| [architecture.md](architecture.md) | La definición de producto y arquitectura — el documento fundacional |
| [workshops.md](workshops.md) | El plan de las 4 sesiones: fechas, qué hace cada equipo cada tarde, riesgos |

## Decisiones y reuniones

| Doc | Qué cuenta |
|---|---|
| [reunion-equipos.html](reunion-equipos.html) | **La reunión de equipos**: frases locales (banco vs modelo), las 8 emociones y las capas, equipos y líderes, BOM y cableado |
| [brief-presentacion.md](brief-presentacion.md) | El brief original de presentación al lab |
| [ideas-exploration.html](ideas-exploration.html) | Registro de ideas exploradas: qué se descartó y por qué |

## Referencia técnica

| Doc | Qué cuenta |
|---|---|
| [event-registry.md](event-registry.md) · [.html](event-registry.html) | **El contrato entre equipos**: los 17 eventos del bus, dueños por prefijo, agujeros conocidos |
| [pack-format.md](pack-format.md) | Formato de packs de personalidad (borrador para discusión) |
| [markov.html](markov.html) | **Cadenas de Markov**: de dónde salen las frases, con el laboratorio para pegar tu corpus y medir la variedad |
| [config-api.md](config-api.md) | Esquema de configuración, secretos, aprovisionamiento por SoftAP y QR (propuesta) |
| [hardware.md](hardware.md) | BOM completa, pedidos, sensores, alimentación y montaje |
| [../hardware/](../hardware/) | Guías de cableado por placa (S3 y clásico) |
| [services.md](services.md) | Proveedores externos: LLM, STT, TTS — cuentas y costes |
| [firmware-architecture.html](firmware-architecture.html) | Arquitectura del firmware, interactiva |
| [arquitectura.html](arquitectura.html) | Arquitectura general, interactiva |

## Modelo de IA local

| Doc | Qué cuenta |
|---|---|
| [local-model-bringup.md](local-model-bringup.md) | Paso 0: ¿puede el chip correr un modelo? (sí — medido) |
| [training-workshop.md](training-workshop.md) | **La sesión de entrenamiento**: de cero a un modelo propio, con la escalera de tamaños |
| [param-explorer.html](param-explorer.html) | Explorador interactivo de parámetros para el proyector |
| `spikes/tinylm-s3` (rama `spike/tinylm-s3`) | El kernel optimizado: 31 → 152 tok/s, con cada paso medido |

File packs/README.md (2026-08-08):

# Packs de personalidad

Un pack es lo que hace que un buddy sea *tu* buddy: reflejos, caras, frases y
assets en un directorio. Se edita desde la web del dispositivo y se recarga en
caliente — sin recompilar, sin reflashear. Comprimido, es un «cartucho» que se
puede compartir.

- **Formato y contrato**: [../docs/pack-format.md](../docs/pack-format.md)
  (borrador — se convierte en spec cuando el grupo lo bendiga).
- **`zero/`** — el pack semilla de Buddy Zero. Su
  [`reflexes/main.be`](zero/reflexes/main.be) es la demo del framework: 40
  líneas de Berry que definen cómo reacciona a caricias, toques y tarjetas
  NFC. Empieza leyéndolo — se entiende sin saber Berry.

Para escribir frases o diseñar caras no hace falta saber programar: el equipo
de personalidad y contenido es la puerta de entrada más fácil al proyecto.

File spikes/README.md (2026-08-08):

# Spikes — experimentos desechables

Un spike es un proyecto pequeño y aislado para responder UNA pregunta con
números, barato de tirar si la respuesta es «no». La disciplina:

1. Rama `spike/<nombre>`, proyecto propio en `spikes/<nombre>/`.
2. El spike **no toca `firmware/`** — el buddy que funciona nunca está en
   riesgo.
3. A `main` solo se mergean las **conclusiones** (README con números medidos
   o un doc en `docs/`), no el código.
4. Un «no» bien argumentado es un resultado válido y valioso.

## Los que existen

- **`lovyangfx-gc9a01/`** (en `main`) — ¿qué librería gráfica? Respuesta:
  LovyanGFX para panel/sprites/fuentes + nuestro renderer SDF para los ojos,
  con caché. Registra las trampas (endianness de sprites, el coste real del
  renderer) que luego evitaron días de depuración.
- **`tinylm-s3/`** (rama `spike/tinylm-s3`) — ¿puede el S3 generar frases con
  un modelo propio? Respuesta: sí — 152 tok/s tras optimizar el kernel
  (4,85×), con cada paso medido y commiteado. Sus conclusiones están en
  [../docs/local-model-bringup.md](../docs/local-model-bringup.md) y
  [../docs/training-workshop.md](../docs/training-workshop.md).

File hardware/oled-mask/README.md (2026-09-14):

# Máscara del OLED — histórico

**Esto no es parte del buddy actual.** Es la máscara imprimible para la
pantalla SSD1306 monocroma de 128×64 de la prueba de concepto original sobre
ESP32 clásico. Ese backend se retiró del firmware: hoy el buddy usa la
pantalla redonda GC9A01 a color.

Se conserva porque la máscara imprime bien y alguien podría querer el PoC
mono para otra cosa. Para el buddy de verdad, usa
[`../round-mask/`](../round-mask/).

El firmware de aquella PoC vive en el historial de git; el commit que retiró
el backend explica por qué.

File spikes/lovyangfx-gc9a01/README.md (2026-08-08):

# Spike: LovyanGFX en ESP-IDF v6.0.2 + GC9A01

Un proyecto desechable en un **segundo** montaje S3 + GC9A01, para que el
buddy PoC que funciona nunca tenga que desmontarse. Desechable por diseño —
si el veredicto es "no", se borra el directorio.

## La pregunta

¿Es LovyanGFX mejor sustrato para la capa gráfica del buddy que nuestro
código a mano de `esp_lcd` + framebuffer en
`firmware/components/expressions/round_face.cpp`?

**No** es una alternativa a LVGL — LovyanGFX son primitivas de dibujo y un
driver de panel, LVGL es un toolkit de widgets. Se componen. Lo que LovyanGFX
sustituiría es *nuestro* código: setup del panel, la fontanería de
`put`/`blend_at`/`clear`/`push`, y la fuente 5×7 `kFont57` escrita a mano.

## Puerta 0 — ¿siquiera compila en ESP-IDF v6.0.2? ✅ PASADA

Este era el riesgo real: la v6 eliminó las APIs legacy de driver que forzaron
nuestra propia reescritura, y LovyanGFX mete la mano hondo en los periféricos
SPI/LCD.

| | |
|---|---|
| Commit de LovyanGFX | `3f78b70`, 2026-07-22 (mantenido activamente) |
| Resultado del build | **limpio, exit 0** |
| Coste en flash | **37.642 B** (27.722 text + 9.484 rodata) |
| RAM estática | 436 B |
| Warnings | 3, todos el mismo — ver abajo |

37 KB es mucho más barato de lo esperado. Contra los 1,86 MB de margen de la
partición de app de 3 MB, el coste es un no-tema.

El único warning es `ledc_channel_config_t::intr_type is deprecated` en
`Light_PWM.cpp` — el helper PWM de retroiluminación de LovyanGFX. Cosmético,
y evitable del todo atando BL a 3V3 y poniendo `pin_bl = -1`.

## Setup

LovyanGFX **no** está vendorizado (40 MB de historia git, y quizá no lo
conservemos):

```bash
git clone --depth 1 https://github.com/lovyan03/LovyanGFX.git components/LovyanGFX
```

El cableado es idéntico al buddy real (ver
`../../hardware/buddy-s3-display.md`) para que cada medición se transfiera
sin paso de traducción de pines.

```bash
source ~/.espressif/tools/activate_idf_v6.0.2.sh
idf.py set-target esp32s3
idf.py -p /dev/cu.usbmodemXXXXXXX build flash monitor
```

**Pasa `-p` siempre.** Con dos placas en la mesa, un `idf.py flash` a secas
sobrescribe alegremente el buddy que funciona.

## Qué prueba el firmware, en orden

1. **Orden de color** — cuatro muestras etiquetadas. La palabra debe
   coincidir con el color. ROJO mostrando azul → invierte `cfg.rgb_order`.
   Negativo fotográfico → invierte `cfg.invert`. Nuestra ruta `esp_lcd`
   necesitó `invert=true` + BGR; esto comprueba si LovyanGFX acierta el
   GC9A01 por sí solo.
2. **Orientación** — "BUDDY" debe leerse de izquierda a derecha. Nuestra
   ruta `esp_lcd` salía en espejo y necesitó
   `esp_lcd_panel_mirror(panel, true, false)`. Si esto sale bien de fábrica,
   ese riesgo de regresión queda retirado.
3. **Calidad de texto** — una muestra de texto pequeño. Es el listón de
   legibilidad que nuestra fuente 5×7 tiene que superar, y la respuesta
   directa a "fuente más pequeña, más texto" sin escribir a mano otra fuente
   de bitmap (la última traía un desbordamiento de buffer que reiniciaba el
   dispositivo con respuestas largas de Claude).
4. **Tiempo de frame** — 60 pushes de pantalla completa, reportado como
   ms/frame y fps.
5. **Coste de sprite** — un sprite PSRAM de 240×240 (112 KB, igual que
   nuestro framebuffer actual) dibujado y empujado 60×. Es a la vez la
   primitiva de "volar alrededor del buddy" y la superficie donde
   renderizaríamos los ojos SDF.

## Resultados

Rellenados desde el log serie. Puerta de adopción: tiempo de frame no peor
que la ruta `esp_lcd` actual, y colores/orientación correctos sin pelea.

| Medición | Resultado |
|---|---|
| Orden de color correcto de fábrica | **sí** — sin pelea de `rgb_order` |
| Orientación correcta de fábrica | **sí** — el texto se lee del derecho, sin mirror |
| `fillScreen` | **24,01 ms/frame (41,6 fps)** |
| Dibujo+push de sprite | **30,78 ms/frame (32,5 fps)** |
| PSRAM para un sprite 240×240 | **116.740 B** |
| RAM interna de `lcd.init` | 2.352 B |

### La importante: estamos limitados por el cable, no por la CPU

240×240×2 B a SPI de 40 MHz son **23,04 ms de puro tiempo de cable**. Medimos
24,01 ms — LovyanGFX logra ~96% del ancho de banda teórico del bus. No queda
nada que optimizar dentro de la librería, y nuestra propia ruta `esp_lcd`
paga exactamente los mismos 23 ms, así que adoptar esto no puede costarnos
frame rate.

Las únicas dos palancas sobre el frame rate son por tanto:
- **subir el reloj SPI** (muchos clones del GC9A01 van a 80 MHz → ~12 ms), y
- **empujar rectángulos sucios en vez de frames enteros** (los ojos son una
  fracción pequeña de 240×240).

Ambas aplican igual a nuestro renderer actual. Conviene saberlo antes de que
alguien gaste una sesión "optimizando el código de dibujo" — el dibujo nunca
fue el problema.

## Test 2 — el escaparate de ojos, y una corrección

Cinco renderizados de la misma emoción, rotando en pantalla. **Son opciones
para que el grupo elija, no una propuesta de que una sea mejor.**

| | |
|---|---|
| A SHIPPED | exactamente lo que `round_face.cpp` dibuja hoy: color plano + glow |
| B DITHERED | + gradiente vertical, con dithering ordenado para que RGB565 deje de hacer bandas |
| C CATCHLIGHT | + un brillo especular — la mayor señal de "vivo" en animación de personajes |
| D DEPTH | + sombreado de borde interior, para que el ojo se lea como lente y no como pegatina |
| E LGFX NATIVE | `fillSmoothRoundRect`; **no puede** hacer la ceja ni el guiño |

Medido, ms por frame, sprite en RAM **interna** (cabe — 115 KB de ~380 KB):

| emoción | A draw | B draw | C draw | D draw | E draw | push |
|---|---|---|---|---|---|---|
| sleepy | 30,6 | 35,2 | 37,9 | 39,5 | 1,8 | 23,1 |
| happy | 62,9 | 69,6 | 73,6 | 76,0 | 2,5 | 23,1 |
| neutral | 64,3 | 76,2 | 82,6 | 87,2 | 2,6 | 23,1 |
| angry | 69,1 | 78,4 | — | — | — | 23,1 |
| curious | 80,4 | 96,2 | 104,4 | — | — | 23,1 |
| **surprised** | **102,4** | 123,8 | 134,7 | **142,7** | 3,3 | 23,1 |

### Corrección: estamos limitados por CPU, no por el cable

El benchmark anterior de `fillScreen` dijo "limitado por el cable" — pero
`fillScreen` es un memset y un push, y nunca toca las cuentas del ojo. Con el
renderer real, **nuestro dibujo SDF del ojo cuesta 1,3×–4,4× el tiempo de
cable.** Una cara completa son 54 ms (sleepy) a 125 ms (surprised) →
aproximadamente **8–19 fps**, y la CPU es el cuello de botella.

Es casi seguro por esto que la cara se sentía lenta. No es el panel, no es el
reloj SPI y no es LovyanGFX — es nuestro bucle por píxel, que llama a `sqrtf`
en cada píxel de la caja del ojo más un margen de glow de 10 px.

## Test 3 — optimizar el renderer

Cinco cambios, todos en el bucle interior, ninguno ingenioso:

1. **`-O2` para este componente** (el proyecto es `-Os` global — correcto
   para el firmware, incorrecto para un bucle por píxel).
2. **Saltarse el `sqrtf`** — `outside` solo es distinto de cero en las
   cuatro esquinas redondeadas. En el resto estábamos calculando `sqrtf(0)`
   o `sqrtf(v*v)`.
3. **Izar el término por fila** — `qy` depende solo de `y`, y se recalculaba
   para cada píxel de la fila. Más un `continue` temprano para píxeles más
   allá del radio del glow.
4. **Izar los colores por ojo** — `rgb(em.r/4, ...)` se recalculaba por
   píxel.
5. **Saltarse el leer-modificar-escribir donde el ojo es opaco** — que es la
   mayoría de sus píxeles, y no hay nada detrás contra lo que mezclar.

| emoción · variante | antes | después | ganancia |
|---|---|---|---|
| neutral · A SHIPPED | 64,29 | **42,74** | −34% |
| happy · A SHIPPED | 62,93 | **45,81** | −27% |
| curious · A SHIPPED | 80,38 | **53,47** | −33% |
| neutral · D DEPTH | 87,15 | **66,74** | −23% |

Una cara neutral completa son ahora **65,9 ms** (42,7 dibujo + 23,2 push)
contra 87,5 ms antes — cerca de **15 fps, desde 11**. El push sigue intacto
en 23,1 ms, como se esperaba; es el cable.

**El intercambio, ya cuantificado:** incluso optimizado, nuestro renderer SDF
es ~16× el coste del `fillSmoothRoundRect` de LovyanGFX (2,6 ms). Lo que eso
compra es la ceja inclinada y el guiño de felicidad, que la primitiva de la
librería no puede expresar en absoluto. Esa es la decisión para el grupo, y
ya no es cuestión de opinión.

**La mayor palanca restante, aún sin probar:** cachear el ojo renderizado. El
bitmap del ojo solo cambia en un parpadeo o cambio de emoción — una sacada en
reposo es una *traslación* de una forma que no cambió. Blitear un ojo
cacheado con offset de mirada dejaría la mayoría de frames a coste de dibujo
casi cero, quedando solo el push de 23 ms. Aritmética de punto fijo y pushes
de rectángulos sucios son las dos siguientes.

### El bug del gradiente (por qué B se veía plano en el panel)

El primer intento usó `k = 1.18 - 0.62t`, aclarando la parte alta del ojo.
Pero el azul de neutral ya es **255**, así que escalar por encima de 1.0 solo
recorta: el tercio superior del ojo quedaba clavado en azul máximo y luego
caía en escalones de ~6 px. Región plana seguida de escalones visibles se lee
exactamente como "sin gradiente, cambios duros de color", que es lo que
parecía.

Encontrado volcando el buffer del sprite por serie en vez de entrecerrar los
ojos frente al panel — los números mostraron `b5=31,31,31,31,30,29,...` de
inmediato.

Arreglo: `k = 1.0 - 0.55t` (nunca pasa de 1.0), y la amplitud del dithering
subida de un paso de cuantización a 1,5, porque un paso apenas rompe una
banda a esta distancia de visión. La columna ahora baja `g6 46→22, b5
30→14`, monótona desde el píxel de arriba.

Para contraste, la primitiva propia de LovyanGFX dibuja en **1,8–3,3 ms**,
25–40× más rápido — pero no puede expresar la ceja ni el guiño, porque esos
se recortan de la forma como *cobertura*, no se dibujan como formas. Ese es
el intercambio real a discutir: expresividad vs un orden de magnitud de CPU.

### La trampa del orden de bytes (nos costó una tarde — lee esta)

**LovyanGFX guarda los sprites de 16 bpp en BIG-ENDIAN**, porque ese es el
orden de bytes que consume el bus SPI. `getBuffer()` te da ese buffer crudo.
Escribir `uint16_t` RGB565 little-endian nativo en él — lo obvio, y lo que
`round_face.cpp` hace con su propio framebuffer — está mal, y mal de una
forma fácil de diagnosticar erróneamente:

- un color **plano** byte-swapeado da un color sólido pero *equivocado* (el
  rojo sale azul-morado), que se lee como bug de paleta;
- un **gradiente** byte-swapeado da *franjas arcoíris horizontales*, porque
  el byte bajo que lleva el azul se convierte en el canal rojo y cicla
  rápidamente rampa abajo.

Demostrado con una carta de prueba que dibuja los mismos tres colores de
tres maneras. La fila 1 (API de LovyanGFX) y la 3 (crudo, byte-swapeado)
salieron correctas; la fila 2 (crudo, little-endian) renderizó R/G/B como
Azul/Rojo/Verde. Las filas 1 y 3 se confirmaron byte-idénticas en el
dispositivo (`0x00F8` / `0xE007` / `0x1F00`), así que escribir el buffer
directamente no cuesta nada en calidad frente a la API de la librería — lo
que importa, porque el renderer SDF necesita acceso por píxel y no puede
usar `fillRect`.

Arreglo: convertir solo en la frontera del buffer (`to_store` /
`from_store`), y pasar `spr.color565(r,g,b)` — nunca un `uint16_t` 565
crudo — a cualquier llamada de LovyanGFX.

**Nota de metodología.** La primera ronda de capturas del framebuffer se
decodificó con la misma suposición little-endian con que se escribió, así
que estaban de acuerdo consigo mismas y no mostraban nada. Lo que cazó esto
fueron fotografías del panel real. Un volcado solo es evidencia cuando se ha
contrastado contra el cristal al menos una vez.

### Notas de arranque (nos costaron 20 minutos, te costarán lo mismo)

- La placa llegó corriendo un firmware que presentaba un puerto **TinyUSB
  CDC** (`0x303A:0x4001`). El auto-reset de esptool no tiene con quién
  hablar en esa interfaz, así que falla con *"No serial data received"*
  aunque el puerto abra bien. El modo download manual (mantener BOOT, tocar
  RESET, soltar BOOT) hace que la ROM presente `0x303A:0x1001` "USB
  JTAG_serial debug unit" en su lugar.
- Tras flashear, **suelta BOOT antes de resetear** o la ROM vuelve directa a
  `boot:0x0 (DOWNLOAD)` y la app no corre nunca.
- El USB-C de esta placa va a los pines USB nativos, así que la consola debe
  ser `CONFIG_ESP_CONSOLE_USB_SERIAL_JTAG=y` — la consola UART0 por defecto
  no sale por ningún sitio visible.
- El devkit tiene un **segundo** USB-C tras un puente CH343. Es mejor para
  flashear (el auto-reset siempre funciona) pero **inútil para volcados de
  framebuffer**: 153 KB a 115200 sin control de flujo pierde bytes, y un
  byte perdido desalinea todo el stream base64 en basura rasgada. Usa el USB
  nativo para todo lo que mueva datos a granel. Cada volcado lleva ahora un
  checksum para que la corrupción se detecte en vez de renderizarse en
  silencio.

## Lo que NO entregaríamos

El renderer de ojos. `sd_round_rect` más multiplicación de cobertura es lo
que hace funcionar la ceja inclinada y el guiño — se recortan del ojo como
*cobertura*, no se dibujan como formas, y `fillSmoothRoundRect` no puede
expresar eso. El plan si esto se adopta: conservar la matemática SDF del
ojo y renderizarla en un `LGFX_Sprite` en vez de nuestro `s_fb` crudo.

Nota también que LovyanGFX **no** arregla el problema del coloreado del ojo.
Eso es banding de profundidad RGB565; el panel sigue siendo de 16 bits. El
dithering o el trabajo de paleta es nuestro en cualquier caso.

## Test 4 — puedes tener las formas Y el frame rate

El veredicto del lab sobre el test 2: conservar la expresividad de A/B,
conservar la fluidez de E, descartar el catchlight. Y un desafío directo a
mi afirmación de que las primitivas de la librería no podían hacer la ceja —
*"no me creo que no podamos tener esas formas (aunque sea con otra
técnica)"*.

**Ese desafío tenía razón y mi afirmación estaba equivocada.** Dos enfoques,
ambos funcionan:

| variante | qué es | fps | aspecto |
|---|---|---|---|
| A SHIPPED | el renderer de hoy, color plano | 15,4 | línea base |
| B GRADIENT | gradiente con dithering + glow | 13,0 | el aspecto preferido |
| **C CACHED** | **los píxeles exactos de B, el SDF corre solo al cambiar emoción/parpadeo** | **32,1** | **idéntico a B** |
| D PRIMITIVE | `fillSmoothRoundRect` + oclusión con triángulo negro | 39,4 | plano, sin glow, formas correctas |

**C es la respuesta.** Una sacada es una *traslación* de una imagen que no
cambió, así que cuesta un blit y no un re-render. Cachear los tres niveles
de apertura por emoción (3 × 115 KB en PSRAM) lleva a B de 13 fps a 32 — una
ganancia de 2,5× con salida píxel-idéntica. El coste es una reconstrucción
de ~110 ms al cambiar la emoción, que es una vez por reacción y se lee como
un compás natural, no un tirón.

**D demuestra que las formas no son exclusivas del SDF.** Dibuja el ojo
entero con la primitiva de la librería y pinta un triángulo negro encima de
la región que la ceja quita — sustracción en vez de multiplicación de
cobertura. La inclinación de enfado sale correcta. Pierde el gradiente y el
glow, pero la geometría está, así que "la primitiva no puede expresar la
ceja" era simplemente falso.

Tanto C como D están cerca del techo físico: los 23,1 ms de cable limitan el
panel a ~43 fps a SPI de 40 MHz, así que 32 vs 39 fps es una brecha
perceptiva mucho menor que 13 vs 39. Subir el reloj SPI levanta ambos.

**Sin resolver entonces e independiente de la técnica:** `browAmt = open *
0.5` rebanaba la mitad de la altura del ojo, y cada variante reproducía las
mismas cuñas. Era un bug de geometría, no de técnica de renderizado.
*(Posdata: arreglado después en el firmware — `kBrowDepth = 0.24` en
`round_face.cpp`; las cejas de angry/sad/suspicious se ven bien desde
entonces.)*

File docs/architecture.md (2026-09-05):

# Definición de producto y arquitectura

Estado: propuesta (pre-HackLab). Las decisiones marcadas **[decidido]**
reflejan la posición de trabajo actual; todo lo demás está abierto al grupo.

## 1. Identidad del producto **[decidido]**

Compañero primero. El buddy es una criatura de escritorio con personalidad —
piensa en Tamagotchi / Anki Vector, no en Alexa-con-cara. El framework tiene
que hacer excelente el bucle *expresivo* (reaccionar, gesticular, piar,
conversar). La utilidad es una superficie de extensión, no un entregable
fundacional: el framework trae el enchufe (Skills), la comunidad trae los
electrodomésticos.

Consecuencia para el alcance: los chirps y los gestos en pantalla (estilo
Animal Crossing) son el canal expresivo *nativo* del buddy — funcionan sin
internet, son gratis y llevan la personalidad. **La voz push-to-talk es meta
de v1 encima de eso** (ver §7 sobre por qué PTT en concreto es abordable en 4
sesiones), y la wake word es explícitamente v2. Cuando la voz no está
disponible (offline, sin API key, pipeline roto) el buddy degrada a chirp +
texto — nunca un ladrillo, y la demo del taller nunca depende del subsistema
más arriesgado.

## 2. Dónde vive el cerebro: primero el dispositivo, hub opcional **[decidido]**

La regla del protocolo único: el firmware nunca habla con "OpenAI" ni
"Anthropic" ni "el hub" — habla con **un endpoint de Brain** con un contrato
pequeño:

```
device → brain:  { event, personality_context, sensor_snapshot, user_input? }
brain → device:  { utterance?, emotion, actions[] }        (streamed)
```

Tres implementaciones intercambiables de ese contrato:

1. **Adaptador cloud en el dispositivo (por defecto).** Un adaptador C++ fino
   formatea la petición para la API de un proveedor LLM directamente sobre
   TLS. Funciona solo con WiFi + una API key. Esto es v1.
2. **Cerebro en hub (opcional, después).** El mismo contrato servido por un
   servidor compañero (cualquier Pi/portátil). Apuntar el dispositivo a un
   hub desbloquea lo que un ESP32 pelado genuinamente no puede: recibir
   webhooks (el dispositivo está tras NAT), integraciones OAuth
   (correo/calendario), memoria a largo plazo, modelos más baratos o locales.
3. **Sin cerebro (offline).** Los reflejos siguen corriendo. El buddy está
   vivo, solo que no conversa. Nunca un ladrillo.

Para "consultar datos externos" sin hub, el dispositivo puede hacer
**polling** (feeds de calendario, RSS, un relay serverless) — el polling es
un Sense, no una Skill, y no necesita conectividad entrante.

Los secretos (API keys, WiFi) viven en la NVS del dispositivo, se meten por
la web UI y nunca van en packs — los packs deben poder compartirse sin filtrar
claves.

## 3. Stack de firmware **[decidido]**

- El **núcleo ESP-IDF (C++)** es dueño de la capa dura/tiempo-real: driver de
  pantalla + renderizado, audio I2S entrada/salida, tacto, WiFi + TLS, el bus
  de eventos, OTA, el servidor web embebido y los adaptadores de Brain.
- La **VM de scripting Berry** (el patrón de Tasmota) es dueña de la capa de
  comportamiento: reflejos, mapeos de expresión, comportamientos de reposo.
  Los scripts se suben y recargan en caliente desde la web — cambiar el
  comportamiento nunca significa reflashear. (Lua es el plan B si la
  integración de Berry se nos resiste; el criterio de decisión es la fricción
  con ESP-IDF, evaluada en la sesión 2.)
- **Por qué no MicroPython para todo:** baja la barrera de contribución, pero
  pelea con el pipeline de audio y se apodera del firmware entero; la
  división núcleo C++ + VM pequeña mantiene un framework estable que los
  miembros del lab raramente tocan, con toda la superficie divertida en
  scripts.

## 4. Bus de eventos y primitivas

Todo es un evento: `touch.pet`, `touch.poke`, `timer.idle`,
`brain.reply`, `webhook.*` (solo hub). Los comportamientos
se suscriben a eventos y emiten acciones: `face.play(anim)`,
`sound.chirp(mood)`, `say(text)`, `gpio.set(...)`, `brain.ask(...)`.

El registro completo de eventos, con dueños por prefijo y agujeros conocidos,
es [event-registry.md](event-registry.md).

- Los **Senses** son drivers C++ registrados en el bus (tacto, nivel de
  micro, GPIO, timers, pollers). Añadir un *nuevo tipo* de sensor es una
  contribución C++; usar uno existente es nivel script.
- Las **Expressions** igual: renderer de cara, reproductor de sonido, LED, y
  después motores. La interfaz está diseñada para que los actuadores encajen
  sin cambios del núcleo.
- Los **Reflexes** son handlers Berry — aquí ocurre el 90% del hackeo.
- Las **Skills** son herramientas expuestas al LLM por el Brain que esté
  activo. El cerebro dispositivo-cloud no trae ninguna (v1); el del hub aloja
  las de la comunidad.

## 5. Packs de personalidad

Un pack es un directorio (subido como zip por la web, guardado en flash/SD):

```
pack.json        nombre, autor, versión, system_prompt, config de voz/chirp
reflexes/*.be    scripts Berry
faces/*          sprite sheets / definiciones de animación
sounds/*         chirps, efectos (PCM/MP3)
```

El framework trae un pack `default` bien hecho que a la vez es el tutorial:
cada mecanismo que ofrece el framework, demostrado en el pack.

**Packs de contenido (capa de almacenamiento SD).** Los packs pueden
referenciar una biblioteca `media/` en la tarjeta micro SD (el VFS hace
transparente flash vs SD — es solo una ruta). Esto habilita packs pesados en
media y *offline-first*; el ejemplo canónico es el **explicador de juegos de
mesa** (la cafetería de un miembro): una pegatina NFC en cada caja → tap → el
buddy reproduce una narración pre-generada con imágenes y animaciones,
enteramente desde SD. El LLM/TTS en vivo queda solo para las preguntas de
seguimiento. Pre-generar la voz (una llamada TTS al crear el pack, cacheada
para siempre) significa coste cero por reproducción, respuesta instantánea y
ninguna dependencia del WiFi del café — la demo funciona con la red caída,
honrando el "nunca un ladrillo". Los packs tipo kiosco como este deberían
además fijar el system prompt del Brain a la tarea (es un dispositivo de cara
al público — los guardarraíles de tema son parte del pack, no una ocurrencia
tardía).

## 6. Web UI

Servida por el propio dispositivo (sin app, sin cuenta cloud):

- aprovisionamiento WiFi de primer arranque — **modo AP → portal cautivo**
  (la base garantizada: funciona sin tag, sin app, sin PN532)
- ajustes: endpoint del brain, API key, volumen, nombre
- gestor de packs: subir/cambiar/editar packs, recarga en vivo de Berry
- una pestaña de chat/consola: hablar con el buddy por texto y ver el bus de
  eventos en directo (a la vez es la herramienta de depuración — disfrutable
  para hackers)

### Aprovisionamiento WiFi por NFC (mejora, no reemplazo)

Un tag NFC puede llevar credenciales WiFi en el registro NDEF estándar
**Wi-Fi Simple Config** (`application/vnd.wfa.wsc`, el formato de credencial
WPS) — escribible nativamente en Android o con la app "NFC Tools" (iOS vía
app; verificar la ruta exacta antes de prometerla). Flujo: tap del tag → la
pantalla muestra `Connect to <SSID>? pet to confirm` → caricia → conecta y
guarda en NVS. Desplegar varios buddies en una red (el café) se convierte en:
escribir un tag, tap a cada uno.

El portal cautivo sigue siendo el suelo; esto es una capa de comodidad
encima.

**Modelo de seguridad — los tags WiFi son la única excepción gobernada a
"los tags nunca hacen auth":**

1. Las credenciales WiFi se parsean en la **capa framework y nunca entran al
   evento Berry `nfc.tag`** — los packs reciben como mucho una señal sin
   contenido `provision.wifi_seen`, nunca el SSID/contraseña. Esto cierra un
   agujero de exfiltración de credenciales (un pack malicioso esperando un
   tap de WiFi).
2. **La confirmación en pantalla es obligatoria** — cambiar de red es una
   acción privilegiada disparada por datos observados (un tag), así que nunca
   se aplica en silencio. Modo estricto opcional: aceptar tags WiFi solo
   durante una ventana de emparejamiento (primer arranque / mantener para
   emparejar).
3. Advertencia que hay que decirle a la gente: la contraseña está en el tag
   en claro (legible con posesión física + un móvil). Bien para casa/café;
   el tag, fuera del exterior del buddy.

Regla general: exactamente un tipo de tag privilegiado (aprovisionamiento
WiFi), privilegiado *porque* lo maneja el framework con confirmación y cero
exposición de credenciales a los scripts. Todos los demás tags siguen bajo
"solo acciones de lista blanca".

## 7. Voz: push-to-talk en v1, wake word en v2 **[decidido]**

**Primero la verdad de base: STT de vocabulario abierto no puede correr en un
ESP32-S3.** Los modelos clase Whisper necesitan ~100× la memoria y cómputo
del S3. Lo que ESP-SR corre localmente es detección de wake word (WakeNet) y
sets fijos de ~200 comandos (MultiNet) — no dictado. Así que el trabajo del
dispositivo es capturar y streamear audio limpio; el reconocimiento pasa en
la nube (o el hub). El contrato de Brain ya lo asume — la voz añade una ruta
de audio, no una arquitectura nueva.

### v1: push-to-talk (en los talleres)

Mantén la almohadilla (o un botón) para hablar. PTT no es solo prudencia de
alcance — *borra* los dos problemas más difíciles de la voz:

- **Eco/interrupción** → half-duplex. El altavoz está a ~2 cm del micro; la
  cancelación de eco real necesita un canal de referencia loopback que el
  MAX98357A no da. Con PTT, "tocando = escuchando" silencia naturalmente el
  audio del propio buddy. Sin AEC.
- **Fin de frase** → soltar la almohadilla marca el fin. Sin ajustar VAD, sin
  cortar a nadie a mitad de frase.

Pipeline: mantener → silenciar audio + grabar → streamear PCM mono 16 kHz/16
bits (32 KB/s crudo — no hace falta códec en WiFi) a una API de STT →
transcripción al Brain → audio TTS de vuelta por el amplificador.

Notas de ingeniería (donde se van las horas de depuración):
- Los buffers DMA y WiFi deben vivir en RAM *interna* (la PSRAM no vale); una
  conexión TLS cuesta ~50 KB; los framebuffers van a PSRAM.
- Audio fijado al core 1, red/TLS al core 0.
- La latencia (subida → STT → LLM → TTS → bajada) es realistamente de 1,5–3 s
  y no se puede eliminar, solo *enmascarar*: al soltar, el buddy gesticula
  "pensando" al instante (cara + chirp). Ese enmascarado vive en el pack de
  personalidad.

### v2: wake word (post-talleres)

Wake word en el dispositivo vía las instrucciones vectoriales del S3.
Advertencia que el lab debe saber de entrada: WakeNet de Espressif solo trae
palabras pre-entrenadas — un "Hey Buddy" a medida significa pagarle a
Espressif el entrenamiento. La ruta abierta es **microWakeWord** (lo que usa
Home Assistant Voice PE): entrenable por nosotros, corre en el S3. La v2
también reabre los problemas que PTT borró: VAD siempre-encendido para el fin
de frase, y el compromiso half-duplex vs interrupción mientras el buddy
habla. Las APIs realtime/speech-to-speech son un posible atajo que merece un
spike. Chirp+texto sigue siendo primera clase todo el tiempo — la voz es
aditiva.

## 8. Hitos

- **M0 — Está vivo:** placa despierta, cara animada, reacciones al tacto,
  aprovisionamiento WiFi, esqueleto de web UI.
- **M1 — Es hackeable:** bus de eventos + reflejos Berry recargados en
  caliente desde la web.
- **M2 — Es una personalidad:** contrato de Brain + adaptador
  dispositivo-cloud, chat vía web, emociones/chirps movidos por el LLM,
  packs de personalidad.
- **M3 — Escucha:** bucle de voz push-to-talk — mantener para hablar → STT
  cloud → Brain → respuesta TTS, latencia enmascarada con gestos de pensar.
- **M4 — Es tuyo:** carcasa propia montada, pack por defecto pulido, demo.
- **v2+ (post-talleres):** wake word (microWakeWord), cerebro en hub, Skills,
  el módulo **base de potencia** (batería 18650 + carga/boost clase IP5306 +
  cuello con 2× servos MG90S, acoplándose a la carcasa v1 preparada para
  cuello), cartuchos de pack por NFC (stretch de la sesión 4 si da tiempo),
  más placas.

## 9. Referentes que vale la pena estudiar

- **Tasmota** — scripting Berry embebido en ESP32 (el patrón para M1)
- **ESPHome** — firmware guiado por configuración, UX de aprovisionamiento web
- **wire-pod** (Anki Vector) — arquitectura de hub para un robot compañero
- **Willow / Home Assistant Voice PE** — pipelines de voz en ESP32-S3
- **ElatoAI, demos ESP32 de OpenAI realtime** — voz directa dispositivo↔API
  realtime
- **Stack-chan** (meganetaaan) + el oficial **M5StackChan** (ESP32-S3) — el
  primo más cercano: carcasa/placa/firmware abiertos, host
  TypeScript-en-Moddable + "MODs" rápidos (valida nuestra división núcleo
  C++ + scripts con recarga). Su cuello servo pan/tilt y sus soportes
  impresos son la referencia para nuestra base de potencia v2. Contraste en
  soberanía: M5StackChan se configura vía app del fabricante + cuenta + nube
  XiaoZhi; nosotros vía web servida por el dispositivo + claves propias
  ("un Stack-chan sin casero").
- **m5stack-avatar** (MIT) — cara paramétrica: estados de expresión, timing
  de parpadeo, sacadas y **lip-sync por amplitud** (la boca se abre según el
  volumen del TTS). No es drop-in (M5GFX vs nuestro stack) pero el modelo de
  cara se porta; nuestro renderer debería adoptar el lip-sync por amplitud
  desde el día uno — el encanto más barato por línea del género.

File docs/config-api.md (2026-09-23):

# API de configuración — propuesta de contrato

> **PROPUESTA. Nada de esto existe todavía en código.** Es el contrato que
> firmware y web necesitan acordar *antes* de escribir cada uno su mitad, para
> que las dos mitades se encuentren. Una decisión sigue abierta y está marcada
> como tal: la autenticación.
>
> Relacionado: [#5](https://github.com/HackLab-Oriente/desktop-buddy/issues/5)
> (UI de configuración), [#26](https://github.com/HackLab-Oriente/desktop-buddy/issues/26)
> (adaptadores de voz), [#21](https://github.com/HackLab-Oriente/desktop-buddy/issues/21)
> (selección de pack).

## Qué hay hoy

Tres hechos, porque explican por qué este documento existe:

1. **Las credenciales están compiladas.** `BUDDY_WIFI_SSID`, `BUDDY_WIFI_PASS`
   y `BUDDY_ANTHROPIC_API_KEY` viven en `Kconfig.projbuild`. Cambiar de red
   significa recompilar, que va contra las reglas de la casa. El propio
   Kconfig ya lo admite: *«PoC only — v1 stores this in NVS via web UI»*.
2. **La partición NVS existe y nadie la usa.** 24 KB en `0x9000`. El proyecto
   solo llama a `nvs_flash_init()` para el driver de WiFi; no hay namespace
   propio, ni una lectura, ni una escritura. Terreno limpio: no hay nada que
   migrar.
3. **El web UI no tiene autenticación.** Tres endpoints (`GET /`,
   `GET /reflex`, `POST /reflex`) y ninguno pide nada. Hoy eso significa
   «cualquiera en tu WiFi puede cambiar el comportamiento de tu buddy». Con
   config significa otra cosa. Ver [Lo que sigue abierto](#lo-que-sigue-abierto).

## El límite: qué es config y qué es pack

La regla, para no discutirla caso por caso:

> **Si es un secreto, o es sobre la red de *este* buddy, es config. Si es
> sobre *quién es* el buddy, es pack.**

| config (NVS) | pack (LittleFS / SD) |
|---|---|
| WiFi, claves de API, proveedores | prompt de sistema, expresiones |
| qué pack está activo | reflejos Berry, frases, sonidos |
| nombre del dispositivo | la gramática de las tarjetas NFC |

Este límite se rompe callado: el día que el prompt de sistema acabe en NVS
«porque es más fácil de editar», el pack deja de ser portable y regalar un
buddy configurado deja de funcionar.

## El esquema

Versionado desde el primer día: el campo `schema` no cuesta nada ahora y es
imposible de retrofitear después.

```json
{
  "schema": 1,
  "device": { "name": "buddy-a3f2" },
  "wifi":   { "ssid": "HackLab", "psk": "(solo escritura)" },
  "brain":  {
    "provider": "anthropic",
    "model": "claude-haiku-4-5",
    "api_key": "(solo escritura)"
  },
  "voice": {
    "stt": { "provider": "openai", "model": "whisper-1", "api_key": "(solo escritura)" },
    "tts": { "provider": "openai", "voice": "nova",      "api_key": "(solo escritura)" }
  },
  "pack": { "active": "zero" }
}
```

Tres decisiones dentro de ese JSON que no son obvias:

**STT y TTS tienen claves separadas aunque hoy sean la misma de OpenAI.**
Es justo el punto de [#26](https://github.com/HackLab-Oriente/desktop-buddy/issues/26):
los proveedores son intercambiables, y Groq para STT + OpenAI para TTS es una
combinación razonable. Un solo campo `api_key` compartido codifica la
suposición de que un proveedor hace las dos cosas.

**Los proveedores se validan contra una lista, no son texto libre.** Una errata
en `"opanai"` no debe descubrirse como un 401 raro tres capas más abajo; se
rechaza al escribir, con un mensaje que diga cuáles valen. Esto es lógica pura
y se prueba en el host, igual que `ndef.h` y `latin1.h`.

**El formato de la API y el de almacenamiento no son el mismo**, y la razón es
concreta: **las claves de NVS no pueden pasar de 15 caracteres.**
`voice.stt.api_key` son 17. Así que el JSON va anidado y el almacenamiento es
plano, con una tabla de traducción:

| ruta JSON | clave NVS | | ruta JSON | clave NVS |
|---|---|---|---|---|
| `schema` | `schema` | | `voice.stt.provider` | `stt.prov` |
| `device.name` | `dev.name` | | `voice.stt.model` | `stt.model` |
| `wifi.ssid` | `wifi.ssid` | | `voice.stt.api_key` | `stt.key` |
| `wifi.psk` | `wifi.psk` | | `voice.tts.provider` | `tts.prov` |
| `brain.provider` | `brain.prov` | | `voice.tts.voice` | `tts.voice` |
| `brain.model` | `brain.model` | | `voice.tts.api_key` | `tts.key` |
| `brain.api_key` | `brain.key` | | `pack.active` | `pack.active` |

Namespace único: `buddy`. Claves planas en vez de un blob JSON entero por dos
razones: NVS da atomicidad por clave (cambiar el modelo no reescribe la clave
de API), y un blob corrupto se lleva por delante hasta el WiFi.

## Los secretos: una regla, no una lista

> **Todo campo que se llame `api_key` o `psk` es de solo escritura.**

`GET /config` nunca los devuelve. Devuelve el booleano correspondiente:

```json
{ "brain": { "provider": "anthropic", "model": "claude-haiku-4-5", "api_key_set": true } }
```

Regla y no lista enumerada, porque así el proveedor de voz que alguien añada
en marzo lo hereda sin que nadie se acuerde de actualizar nada.

**Consecuencia directa en el bus** — ver la sección siguiente, porque es donde
esta regla se puede perder sin darse cuenta.

Y una advertencia que hay que escribir aunque no la arreglemos: **NVS no está
cifrada por defecto.** Quien tenga la placa en la mano y `esptool` puede sacar
la clave de la flash. ESP-IDF soporta cifrado de NVS sobre flash encryption,
pero complica bastante el flasheo. Para un taller la decisión razonable es no
hacerlo — y dejar constancia de que fue una decisión, no un olvido.

## Los eventos

```
config.changed   payload: nombres de sección, separados por coma → "wifi,brain"
config.setup     payload: el SSID del AP de aprovisionamiento    → "buddy-a3f2"
```

**El payload de `config.changed` son nombres de sección, nunca valores, y esto
no es estilo.** Los packs Berry se suscriben al bus. Si el evento llevara la
config, cualquier pack podría leerte la clave de API en tres líneas de Berry.
Con nombres de sección, el cerebro sabe que tiene que releer su clave y nadie
más se entera de cuál es.

Qué necesita reinicio y qué no, para que la UI pueda decirlo con honestidad:

| sección | efecto |
|---|---|
| `brain`, `voice` | en caliente: el consumidor relee y sigue |
| `pack.active` | en caliente: recarga la VM Berry (el camino ya existe para `POST /reflex`) |
| `wifi` | reconecta — disruptivo, pero sin reiniciar |
| `device.name` | al siguiente arranque (afecta al SSID del AP y a mDNS) |

**Estos eventos no están en [`event-registry.md`](event-registry.md) todavía, a
propósito.** El registro se queja explícitamente de los eventos «documentados
pero no implementados» porque le cuestan una tarde a alguien; entran ahí en el
PR que los implemente. Y `config.*` es espacio del equipo de Web, así que los
nombres finales los firma Juan Esteban.

## Precedencia: Kconfig sigue existiendo

**NVS gana si tiene valor; Kconfig es el valor de fábrica.**

Así los flasheos actuales siguen funcionando (hay `sdkconfig` con credenciales
reales por ahí), NVS pasa a ser una capa de override, y «reset de fábrica»
tiene una definición de una línea: borrar el namespace `buddy`.

Esa regla es además la que resuelve el taller **sin código nuevo**: la red de
la sala entra por `menuconfig` al flashear, los buddies arrancan conectados, y
el día que alguien se lleve el suyo a casa el portal escribe la red nueva en
NVS y gana. La red del taller es el valor de fábrica, no una atadura. Si se
hace, que sea en un `sdkconfig` local sin commitear: la contraseña de la sala
no tiene por qué vivir en un repositorio público.

## Las dos puertas y el núcleo único

La pregunta no es «¿cuántas puertas?» sino «¿cuántas implementaciones?». Una:

```
config_apply(json) → validar → escribir NVS → emitir config.changed
```

Con eso, cada transporte es fino:

| puerta | cuándo | tamaño |
|---|---|---|
| **Portal SoftAP** | primer arranque, o la red de casa ya no existe | la que hay que construir |
| **Web UI normal** | ya está en la red | el `webui` que ya existe |

Que el núcleo esté separado no se justifica por tener muchas puertas: se
justifica porque la validación, la escritura y el evento ocurren en un solo
sitio. Una consola serie de depuración, o lo que venga después, son veinte
líneas en vez de una segunda implementación con sus propios fallos.

### Portal SoftAP

El buddy levanta `buddy-a3f2`, el teléfono se une, el portal pide la red. Es
la única opción que funciona **sin nada más que un teléfono**, y por eso es la
que tiene que existir.

Hay una bifurcación real ahí: usar el componente `wifi_provisioning` de
Espressif (cifrado, probado, pero **necesita su app**) o montar un portal
cautivo propio sobre el `esp_http_server` que ya tenemos (cualquier navegador,
sin instalar nada, pero la HTML y el secuestro de DNS los escribimos
nosotros). Para un taller donde la gente se lleva el buddy a casa, **no
instalar una app vale mucho** — y si el AP va con WPA2, las credenciales no
viajan en claro por el aire aunque el portal sea HTTP.

El portal cautivo se abre solo si el DNS responde a todo con la IP del
dispositivo: iOS sondea `captive.apple.com` y saca la hoja de login, Android
sondea `connectivitycheck.gstatic.com` y saca la notificación. Es un camino
muy trillado, con dos avisos: la hoja de iOS es un WebView limitado —**el
portal tiene que ser HTML simple y pequeño**— y un teléfono con DNS privado
configurado puede no morder el sondeo.

### El QR en la cara

El payload es texto estándar, sin app:

```
WIFI:T:WPA;S:buddy-a3f2;P:8fk29dla;;
```

Son 36 bytes → **QR versión 3** (29×29 módulos), que a ECC-M admite 42. La
pantalla es redonda, así que el cuadrado útil no es 240×240 sino el inscrito:
**169 px**. A 4 px por módulo, con la zona tranquila de 4 módulos que pide la
norma: 37 × 4 = **148 px**, y las esquinas quedan a 105 px del centro contra
un radio de 120. Entra.

**El límite no son los píxeles, son los milímetros.** En un panel de 1,28″
(~32,5 mm) un módulo de 4 px mide 0,54 mm y el código entero unos **20 mm**:
se escanea, pero la ventana útil está sobre los **10–20 cm** y un teléfono con
mal enfoque cercano lo va a buscar un rato. La palanca es el número de
caracteres, y es más empinada de lo que parece — cada carácter puede subir la
versión, y subir la versión encoge *todos* los módulos. **SSID corto.**

Segundo uso, que en el día a día vale más que el primero: ya en la red de
casa, un QR de `http://192.168.40.96/` en la cara mata para siempre la
búsqueda de «cuál era la IP del buddy».

Espressif publica un componente `qrcode` en el registro (lo usan sus ejemplos
de aprovisionamiento), pero no hizo falta: LovyanGFX trae su propio
`qrcode()`, y es el que dibuja la cara.

### Por qué no hay tarjeta NFC de configuración

Se consideró y se descartó. Queda escrito porque la idea es buena y va a
volver.

La propuesta era una tarjeta con la red del taller: un toque, quince buddies
configurados. Al acotarla a **solo la puesta en marcha** —no uso diario— se
quedó sin caso propio:

- **En la puesta en marcha la gente está delante de un portátil.** Las
  sesiones se montan en protoboard y cada uno flashea desde su clon; la red se
  pone una vez en `menuconfig` y ya. La tarjeta no acelera nada ahí.
- **Lejos del portátil ya es uso diario**, que es justo lo que la tarjeta no
  iba a cubrir. Y ese caso es el del portal SoftAP, una vez por persona: no
  hay problema de caudal que resolver.

Los costes, en cambio, eran permanentes:

- **La contraseña del WiFi en claro sobre una pegatina**, sin caducidad y sin
  forma de revocarla. Las tarjetas se quedan en las mesas, se van en mochilas
  y se reescriben luego como cartuchos.
- **El firmware tendría que reclamar un prefijo** (`buddy:config:`) de la
  gramática de las tarjetas, que es del equipo de personalidad. Ese prefijo
  queda reservado para siempre aunque la función se use una tarde.
- **NTAG215 obligatorio** (504 B de usuario) en vez de NTAG213 (144 B): una
  consecuencia de compra para toda la tanda.
- Una superficie de ataque más, y pasiva: nadie confirma nada, se acerca una
  tarjeta y el buddy obedece. Aceptarlas solo en modo setup habría estrechado
  esa ventana, pero la ventana **es** el taller — el rato exacto en que hay
  tarjetas sueltas por todas las mesas.

**Lo que sí queda**: NFC sigue haciendo lo que ya hace bien, cartuchos de
personalidad por `nfc.text`, con la gramática entera en manos del pack. El
firmware no le quita ningún espacio de nombres a nadie.

## Autenticación: decidido en la sesión 1

**El dueño elige.** La configuración lleva un selector con tres modos, y el
firmware no impone ninguno:

| modo | qué pide para escribir | para quién |
|---|---|---|
| `none` | nada | red de casa, y el modo de trabajo mientras desarrollamos |
| `pin` | un PIN de 6 dígitos que sale **en la pantalla** | un taller, un congreso: presencia física como factor |
| `password` | una contraseña que el dueño fija en la configuración | quien administra su buddy sin estar delante |

Las lecturas no piden nada en ningún modo; el selector cubre las escrituras.
`GET /config` no devuelve secretos, así que no hay nada que proteger ahí.

**Por defecto `none`, y en v1 el instalador pregunta.** Durante el desarrollo
nadie quiere teclear un PIN para probar un reflejo, y una autenticación que
estorba se acaba desactivando y no se vuelve a activar.

### Por qué tres y no el PIN solo

El PIN en la pantalla fue lo primero que gustó, y se le encontró el borde en
la misma sesión: **usa la presencia física como factor, así que le cierra la
puerta a quien no está delante.** Quien quiera cambiar la configuración de su
buddy desde otra habitación —o desde la oficina— no tiene forma de leer el
PIN. La contraseña es exactamente esa puerta, y no cuesta nada más que el
PIN una vez existe el selector.

Que sean tres modos y no dos también hace explícito el primero: `none` deja de
ser lo que pasa por inercia y pasa a ser algo que alguien eligió.

### Dos cosas que van decididas pase lo que pase

- **`GET /config` no devuelve nunca un secreto.** Devuelve `"api_key_set":
  true`. La regla es por nombre de campo (`api_key`, `psk`), no una lista
  enumerada que se olvida de actualizar cuando aparece el campo siguiente.
- **NVS no va cifrada.** Quien tenga la placa en la mano y `esptool` saca la
  clave de la flash. ESP-IDF sabe cifrar NVS sobre flash encryption, pero eso
  complica el flasheo lo bastante como para estorbar en un taller. Se acepta,
  **y consta como decisión y no como olvido**.

### Lo que reduce el problema

Si el AP de aprovisionamiento va con WPA2 y la contraseña se enseña como QR en
la cara, **el aprovisionamiento ya queda autenticado por presencia física** —
en el enlace, no en la aplicación, y protegiendo la sesión entera en lugar de
un endpoint. El selector se ocupa entonces solo del web UI en funcionamiento
normal, ya dentro de la red de casa, que es una pregunta mucho más pequeña.

La implementación va en [#54](https://github.com/HackLab-Oriente/desktop-buddy/issues/54); el campo lo define el núcleo de configuración ([#5](https://github.com/HackLab-Oriente/desktop-buddy/issues/5)).

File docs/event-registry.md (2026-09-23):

# Registro de eventos — el contrato del bus

Cada evento que existe, qué lleva, quién lo emite y de quién es el nombre —
y, en una tabla aparte, los que **todavía no existen pero ya están
diseñados**, para que nadie construya contra un nombre creyendo que es real.

Esto es el **contrato entre equipos**. Es la razón de que los tracks puedan ir
en paralelo: el equipo de voz puede construir sobre `voice.*` mientras
firmware sigue con la API de configuración, siempre que ambos lados acuerden
los nombres. Mantén este archivo al día — un registro equivocado es peor que
ninguno.

Dueño: **firmware y arquitectura** (el contrato). Cada equipo es dueño de los
eventos dentro de su espacio de nombres — ver [Espacios](#espacios-de-nombres).

Vista interactiva de este archivo — con buscador y los sitios reales de
publicación y suscripción: [event-registry.html](event-registry.html).

## Cómo funciona el bus

- `bus().publish(name, payload)` encola; la entrega ocurre en `pump()`,
  ejecutado por la tarea del bus. **Los handlers por tanto nunca corren en
  paralelo** y no necesitan locks propios.
- **La capa de reflejos se suscribe a `*`** y pasa todo a la VM de Berry salvo
  `system.reload`. Por eso un pack puede reaccionar a cualquier evento de esta
  página sin tocar el firmware — es la forma más concreta que tiene «el
  comportamiento es datos». Y por eso las columnas de suscriptores de abajo
  están incompletas por diseño: cuentan el firmware, no los packs.
- Lo que un reflejo **no** puede publicar: `system.*`, `config.*`, `boot.*` y
  `pack.*`. Son de firmware y de la web, y la regla la aplica el código.
- `bus().subscribe(pattern, fn)` donde `pattern` es un nombre exacto, un
  comodín de prefijo (`touch.*`) o `*` para todo.
- `Event` es `{ std::string name; std::string payload; }` —
  [bus.h](../firmware/components/bus/include/bus.h). Un string. Los datos
  grandes nunca viajan en el bus; pasa una ruta o un id.
- Los reflejos Berry ven los mismos eventos vía `buddy.on(pattern, fn)`, con
  `ev['name']` y `ev['payload']`.
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

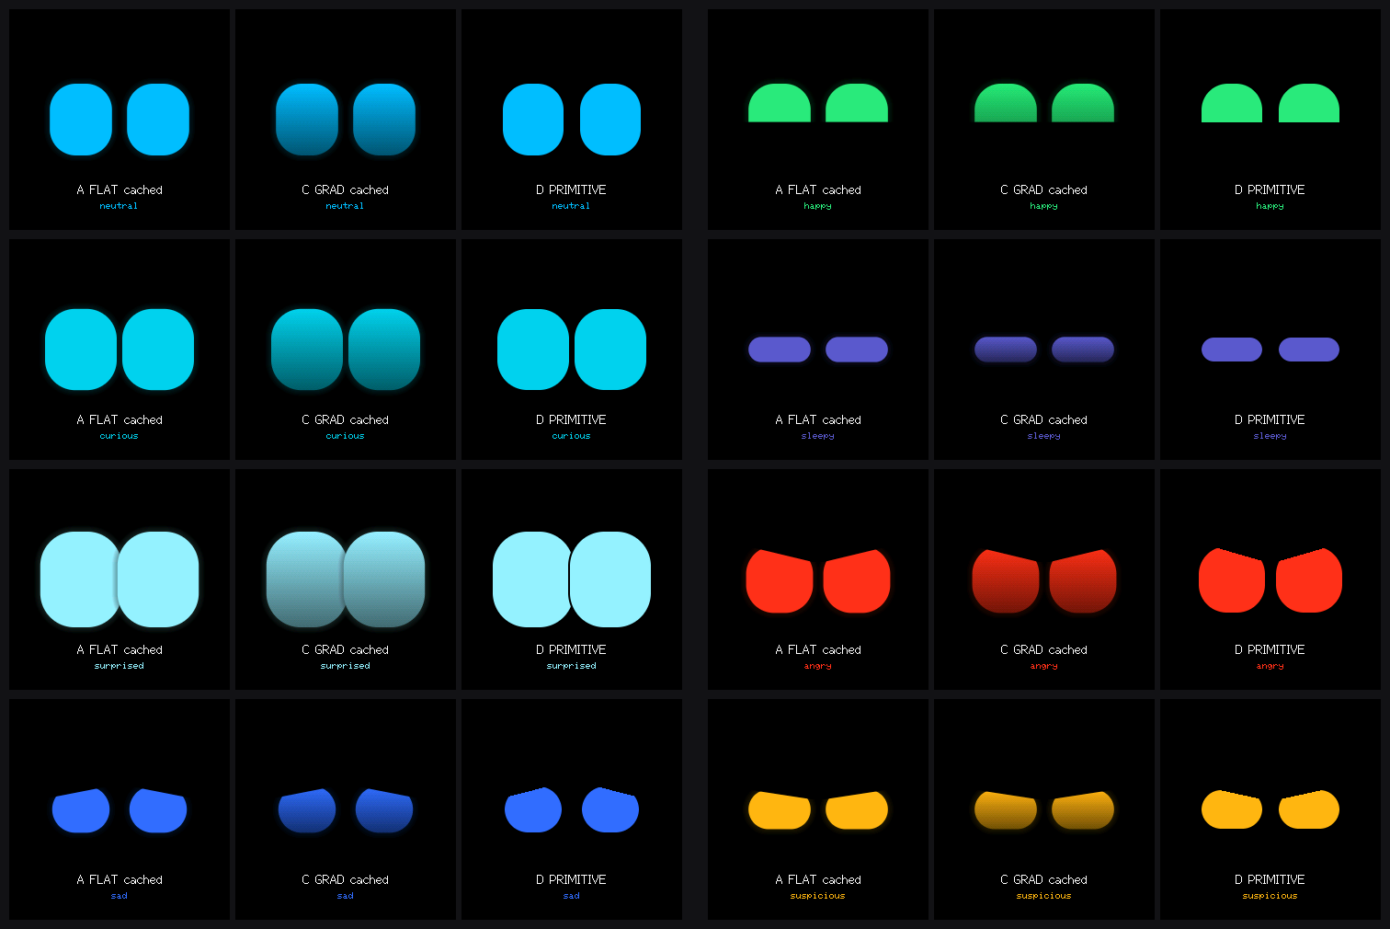
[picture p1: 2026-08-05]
spikes/lovyangfx-gc9a01/eye-variants.png

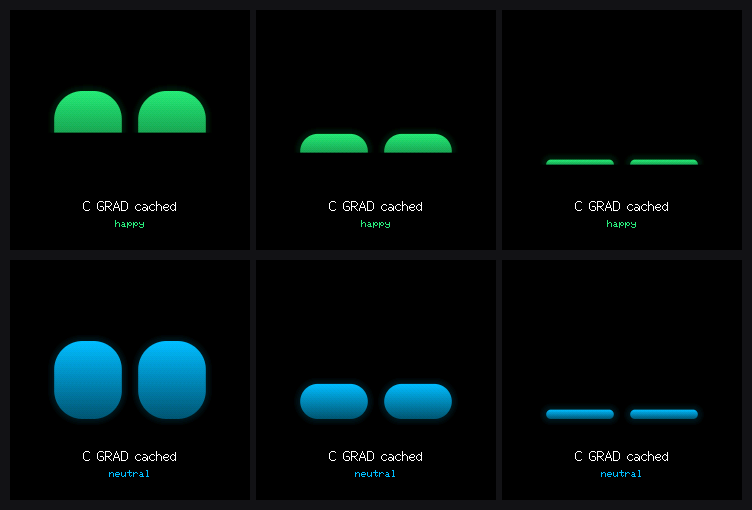
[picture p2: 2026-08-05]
spikes/lovyangfx-gc9a01/blink-progression.png

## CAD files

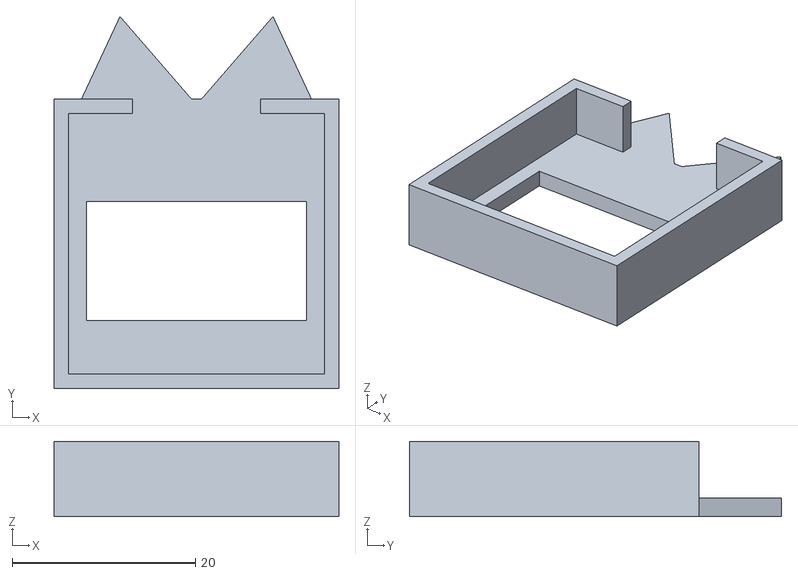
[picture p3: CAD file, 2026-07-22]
hardware/oled-mask/buddy-zero-oled-mask.stl
31.1 x 40.6 x 8.20

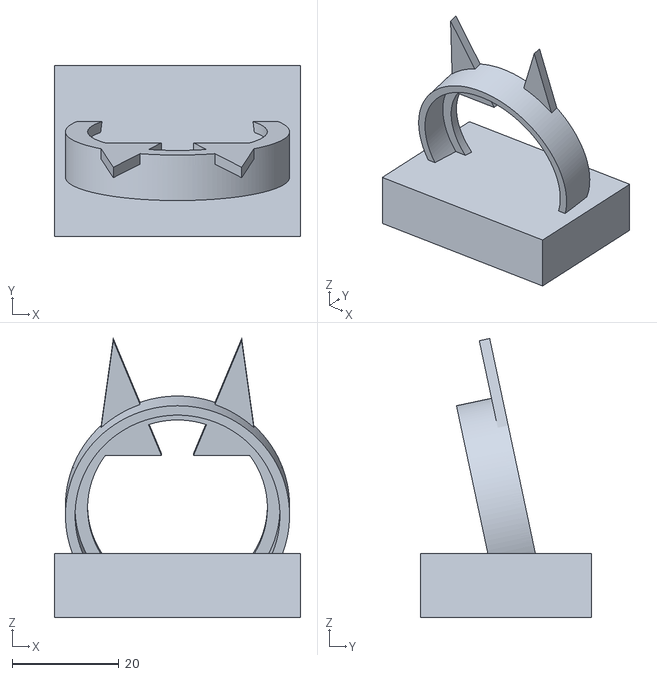
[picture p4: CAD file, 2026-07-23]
hardware/round-mask/buddy-round-mask.stl
46.0 x 32.0 x 52.2

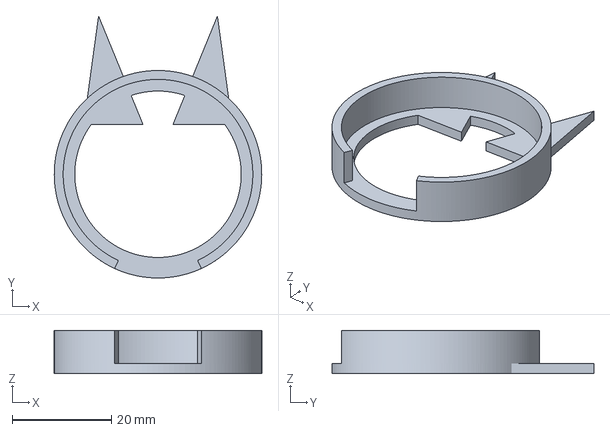
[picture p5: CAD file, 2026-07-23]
hardware/round-mask/buddy-round-mask-no-base.3mf
41.9 x 52.9 x 8.70 mm

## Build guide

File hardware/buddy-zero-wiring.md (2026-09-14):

# Cableado — ESP32 clásico (DevKit V1, 30 pines) · HISTÓRICO

> **El firmware ya no compila para este target.** Se retiró el soporte del
> ESP32 clásico: sin PSRAM no hay caché de ojos ni modelo local, y mantener
> el segundo camino de render —el dibujado por bandas— costaba más de lo que
> daba. Esta guía se conserva porque documenta trabajo hecho y verificado en
> placa, no porque siga vigente. Los pines que cita ya no están en
> `Kconfig.projbuild`. Para la placa de referencia:
> [buddy-s3-display.md](buddy-s3-display.md).
>
> El código del target vivió hasta `0376794`; lo retiró el commit siguiente,
> que explica por qué. Restaurarlo es revertir ese commit. El diagrama
> `buddy-zero.wireviz.yml` que acompaña a esta guía se renderiza con
> [WireViz](https://github.com/wireviz/WireViz).

Era la misma cara a color que el S3, en la placa que muchos ya tenían en el
cajón. **Sigue las etiquetas de la serigrafía, no la posición del pin** — los
clones del DevKit V1 barajan el orden entre fabricantes.

> **Estado**: verificado en placa real con pantalla cableada — arranque,
> animación de boot, ojos, 5 bandas de 23 KB sin costuras visibles, LittleFS y
> tacto V1. Render medido: **69 ms/frame (14,4 fps)**. Lo único aún sin probar
> aquí es el RC522.

## Primero los raíles

- `3V3` del devkit → raíl **rojo** · `GND` → raíl **azul**.
- La pantalla y el RC522 van a **3V3** (el RC522 muere a 5 V). Solo el anillo
  LED usa el pin `VIN`/5V.

## Pantalla GC9A01 (SPI, redonda 1,28″)

| Pin GC9A01 | A | Color sugerido |
|---|---|---|
| VCC | raíl 3V3 | rojo |
| GND | raíl GND | negro |
| SCL | GPIO **18** | amarillo |
| SDA | GPIO **23** | naranja |
| RES | GPIO **26** | blanco |
| DC | GPIO **27** | verde |
| CS | GPIO **5** | morado |
| BLK | GPIO **25** | gris (o a 3V3 y BL=-1 en menuconfig) |

Son los pines VSPI de toda la vida (18/23/5) más tres GPIOs libres. Los pines
del S3 (7–12) **no sirven aquí**: en el clásico 6–11 son la flash del chip.

## Almohadilla táctil

- Un jumper macho pelado en GPIO **4** (T0). El extremo de metal expuesto es
  la almohadilla; luego, pégalo a cinta de cobre para una de verdad.
- En el clásico, tocar **baja** la lectura (en el S3 la sube). El firmware ya
  lo sabe; se menciona porque es la trampa clásica al depurar.

## Anillo WS2812 (12 LED)

| Pin del anillo | A |
|---|---|
| VCC / 5V | **VIN (5V)** — a 3V3 se ve tenue y falla |
| GND | raíl GND (compartido con la placa, obligatorio) |
| DIN | GPIO **21** — el lado DIN, no DOUT |

El brillo está capado en firmware (~35%): 12 LEDs a blanco pleno piden
~700 mA, más de lo que le gusta al 5 V del devkit.

## RC522 NFC (opcional, deshabilitado por defecto)

Actívalo en `menuconfig → Buddy Zero → Enable RC522 RFID reader`.

| Pin RC522 | A | Nota |
|---|---|---|
| 3.3V | raíl 3V3 | **nunca 5 V** |
| GND | raíl GND | |
| SCK | GPIO **14** | |
| MISO | GPIO **34** | solo-entrada: perfecto para MISO y seguro en el arranque |
| MOSI | GPIO **13** | |
| SDA (=CS) | GPIO **15** | el módulo lo serigrafía **SDA**; en SPI es el chip select |
| RST | GPIO **32** | |
| IRQ | — **sin conectar** | el driver hace polling; no usa la interrupción |

Si buscas un pin «CS» en el módulo, no existe: el MFRC522 multiplexa SPI, I2C
y UART sobre los mismos pines físicos y la serigrafía usa el nombre de I2C.
**`SDA` es el chip select.** El `IRQ` se queda al aire a propósito —
`rc522.cpp` lee `ComIrqReg` por SPI en lugar de cablear la interrupción.

MISO va en 34 y no en el clásico 12 a propósito: GPIO 12 es strapping (MTDI),
y un módulo que lo deje alto en el arranque selecciona el voltaje de flash
equivocado. Estos pines están **sin probar en el clásico**. El módulo en sí ya
funciona: en el S3 responde `version 0x92` y lee llaveros a la primera
([buddy-s3-display.md](buddy-s3-display.md)), así que lo único que queda por
demostrar aquí es este mapa de pines.

## Consejos de protoboard

- El DevKit V1 es ancho: ponlo a caballo entre **dos protoboards** (o deja
  una fila de pines colgando del borde) para tener puntos libres a ambos
  lados.
- Los cuatro cables SPI de la pantalla, cortos y de largo parecido.
- El cable del GPIO 4 (tacto) capta ruido: rútalo lejos del mazo SPI.

## Checklist de primer arranque (`idf.py monitor`)

1. `face: frame 240x48 in 5 bands (23040 B), no cache (no PSRAM)` — el
   renderizado por bandas está activo.
2. `touch: baseline=NNN threshold=NNN (touch lowers)` — polaridad V1
   correcta; al tocar el cable caen `touch.down` / `touch.pet` en el log.
3. Ojos parpadeando en la pantalla. Sin imagen: revisa RES/DC/CS y 3V3;
   colores raros: es un clon con otro orden de color (ver
   [buddy-s3-display.md](buddy-s3-display.md), la sección de gotchas vale
   igual aquí).
4. Con RC522: `rc522: MFRC522 version 0x91` (o `0x92`). `0x00`/`0xFF` =
   revisa CS/SCK/MISO/MOSI y alimentación.

## Diagrama como código

`buddy-zero.wireviz.yml` junto a este archivo genera el diagrama del mazo:

```bash
pip install wireviz && wireviz hardware/buddy-zero.wireviz.yml
```

## Qué NO da esta placa

Sin PSRAM no hay caché de ojos (14,4 fps medidos en vez de 30), ni modelo de IA local,
ni el bucle de voz v1. Todo lo demás — bus, reflejos Berry, web con recarga
en caliente, cerebro cloud, NFC — funciona igual que en el S3. La tabla
comparativa está en [../firmware/README.md](../firmware/README.md).

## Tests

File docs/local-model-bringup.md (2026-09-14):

# Arranque del modelo local — Paso 0: probar la ruta de inferencia

**Estado:** HECHO — ejecutado el 2026-08-05. Veredicto: **amarillo, con
margen.** Código y notas completas: rama `spike/tinylm-s3` (los spikes no se
mergean a main). *(Continuación: el Paso 0.5 — la optimización del kernel —
llevó luego el resultado de 31,4 a 152 tok/s; ver el README del spike y
[training-workshop.md](training-workshop.md). Las cifras de este documento
son las del Paso 0 original.)*
**Audiencia:** quien retome esto (humano o agente) antes del Taller 0.

## Qué es esto, y qué no es

Queremos que el buddy genere sus propias frases cortas con carácter en el
dispositivo, con un modelo pequeño entrenado por nosotros (ver "A dónde lleva
esto" al final).

Antes de gastar dinero y un fin de semana entrenando nada, hay que responder
una pregunta con un **número medido**, no una estimación:

> ¿Puede un ESP32-S3 correr inferencia de transformer lo bastante rápido,
> *mientras la cara sigue animándose*, como para que valga la pena?

Este documento trata solo de responder eso. Usa un modelo desechable.

### El modelo desechable: `stories260K`

**`stories260K` NO es el modelo de
[slvDev/esp32-ai](https://github.com/slvDev/esp32-ai), y no es el modelo que
pretendemos entregar.** Tres cosas distintas, fáciles de confundir:

| | Qué | Por qué está aquí |
|---|---|---|
| **slvDev/esp32-ai** | 28,9M params, 4-bit, **14,9 MB** | El proyecto que inspiró esto. **Rechazado**: no cabe en nuestra flash (ver `docs/ideas-exploration.html`). Buena fuente de técnica. |
| **`stories260K`** | ~260K params, fp32, **~1 MB** | **Este documento.** Un benchmark desechable. Su salida es casi galimatías. No nos importa qué dice — solo a qué velocidad lo dice. |
| **El modelo "voz del buddy"** | ~1,3–4M params, 4-bit, ~0,7–2 MB | Lo que de verdad queremos entrenar. Bloqueado por la respuesta de aquí. |

`stories260K` es de [llama2.c](https://github.com/karpathy/llama2.c) de
Andrej Karpathy. Es el benchmark correcto porque es *deliberadamente
diminuto*: la misma familia de arquitectura que entrenaríamos, tan pequeño
que corre en fp32 **sin ningún trabajo de cuantización**, y su motor de
inferencia (`run.c`) es un único archivo C sin dependencias de menos de 1000
líneas. Eso convierte el Paso 0 en un ejercicio de porteo, no un proyecto de
investigación. Si hubiera que escribir primero un kernel de 4 bits, esto
sería un mes en vez de un fin de semana.

## Prerrequisitos

- Placa ESP32-S3 N16R8 con la pantalla redonda ya funcionando (`hardware/buddy-s3-display.md`)
- ESP-IDF v6.1 (`source ~/.espressif/tools/activate_idf_v6.1.sh`)
- La partición `model`, ya añadida a `firmware/partitions.csv` (4 MB, cruda, offset 0x710000)

## Paso 1 — Conseguir el modelo y verificar su forma

```bash
mkdir -p /tmp/l2c && cd /tmp/l2c
git clone --depth 1 https://github.com/karpathy/llama2.c
ls -la llama2.c/stories260K/    # stories260K.bin + tok512.bin
```

Si esa carpeta falta, los modelos están también replicados en
`huggingface.co/karpathy/tinyllamas`. **No te fíes de números de
configuración citados de memoria — léelos del archivo.** La cabecera legacy
de llama2.c son siete int32 little-endian:

```python
import struct
with open('llama2.c/stories260K/stories260K.bin','rb') as f:
    dim, hidden_dim, n_layers, n_heads, n_kv_heads, vocab_size, seq_len = \
        struct.unpack('<7i', f.read(28))
print(f"{dim=} {hidden_dim=} {n_layers=} {n_heads=} {n_kv_heads=} {vocab_size=} {seq_len=}")
# A negative vocab_size means the classifier weights are NOT shared with the
# embedding table — run.c keys off this, so note which one you have.
```

Registra estos números en este archivo cuando los tengas. Todo lo de aguas
abajo (dimensionado de memoria, la extrapolación del Paso 5) depende de
ellos.

## Paso 2 — Flashear los pesos a la partición `model`

Los pesos van **en crudo**, no como archivo, para que se puedan mapear a
memoria siquiera — `esp_partition_mmap` funciona sobre una partición cruda
pero no sobre un archivo dentro de LittleFS. (El Paso 4 descubrió que *no*
conviene ejecutar desde el mapeo: cópialo a PSRAM en el arranque. La
partición cruda sigue siendo el sitio correcto para guardarlo.)

```bash
esptool.py --chip esp32s3 write_flash 0x710000 llama2.c/stories260K/stories260K.bin
```

Confirma el offset contra `firmware/partitions.csv` antes de ejecutar esto —
escribir en el offset equivocado corrompe la app o el sistema de archivos de
packs.

El tokenizer (`tok512.bin`, unos KB) puede ir en LittleFS como archivo
normal; se lee secuencialmente una vez al arrancar, así que no necesita mmap.

## Paso 3 — Portar `run.c` a un componente ESP-IDF

Crea `firmware/components/tinylm/`. Copia `llama2.c/run.c` tal cual y haz
exactamente cuatro cambios. Resiste hacer más — la meta es una medición, no
un buen componente.

1. **Pesos: I/O de archivo → mmap.** Sustituye el bloque `mmap()`/`open()`
   de `build_transformer` por:
   ```c
   const esp_partition_t* p = esp_partition_find_first(
       ESP_PARTITION_TYPE_DATA, (esp_partition_subtype_t)0x40, "model");
   const void* base = NULL;
   esp_partition_mmap_handle_t h;
   ESP_ERROR_CHECK(esp_partition_mmap(p, 0, p->size,
                                      ESP_PARTITION_MMAP_DATA, &base, &h));
   ```
   y apunta los punteros de pesos dentro de `base` exactamente como el
   código original los apunta dentro del archivo mapeado.
2. **Buffers de RunState → PSRAM.** Cada `calloc` de `malloc_run_state` se
   vuelve `heap_caps_calloc(..., MALLOC_CAP_SPIRAM)`. Son las activaciones y
   la KV cache — se escriben en cada token, así que deben estar en RAM, no
   en flash.
3. **Tokenizer desde un array embebido**, no un archivo — un benchmark no
   debería necesitar sistema de archivos. Y **elimina `main()`**.
4. **Añade un `CMakeLists.txt`**: `idf_component_register(SRCS "run.c" INCLUDE_DIRS "include" REQUIRES spi_flash esp_partition)`
   y pon `-ffast-math -O2` solo en este componente.

Luego llámalo desde una tarea fijada al **core 1**, prioridad **3** (por
debajo de la tarea de la cara a 4, para que la cara gane la contención —
queremos medir la cara degradándose, no muriéndose de hambre).

## Paso 4 — Medir

Toma cinco números. Regístralos aquí en la tabla.

| Métrica | Resultado |
|---|---|
| Modelo, leído de su propia cabecera | dim 64, hidden 172, 5 capas, 8 heads, 4 kv-heads, vocab 512, seq 512 |
| Parámetros | 260.672 en total — **227.840 no-embedding** (la parte que cuesta cómputo) |
| tok/s, pesos mapeados desde flash | **12,6** (79,5 ms/token) |
| tok/s, pesos copiados a PSRAM | **31,4** (31,8 ms/token) |
| p50 / p99 por token (PSRAM) | 31,7 / 39,2 ms — muy plano, el jitter no es problema |
| PSRAM consumida | 676 KB, casi todo la KV cache |
| RAM interna consumida | ~17 KB |
| Salida | prosa TinyStories coherente — el porteo es correcto, no solo rápido |

### El hallazgo titular: NO mapees los pesos a memoria

Cada token lee el set de pesos completo, y 1 MB no cabe en la caché de la
MMU — la inferencia mapeada gasta el **60% de su tiempo esperando a la
flash**. Copiar los pesos a PSRAM en el arranque es **2,5× más rápido**, y
para nosotros es gratis: la PSRAM son 8 MB y todos los modelos que
consideramos pesan 0,7–3,4 MB.

Aquí es donde el truco de Per-Layer Embeddings del proyecto esp32-ai deja de
aplicarnos. PLE existe porque un modelo de 14,9 MB *no puede* caber en RAM.
El nuestro cabe, así que simplemente lo dejamos residente y nos saltamos el
problema entero.

## Paso 5 — Extrapolar al modelo real

El coste de cómputo escala con los parámetros **no-embedding** (la tabla de
embedding es una búsqueda, no un matmul). Para `stories260K`, no-embedding ≈
`n_layers × 12 × dim²`. Para nuestra candidata Config S (vocab 1024, d=128,
6 capas) son ~1,18M.

```
predicted_ms_per_token(Config S) ≈ measured_ms_per_token(260K) × (1.18M / non_emb_260K)
```

Luego aplica un **factor de aceleración de 0,5–0,7×** por pesos int4 (menos
tráfico de memoria, más coste de desempaquetado) — y trátalo como una
suposición hasta que alguien lo mida.

### Puertas de decisión — y dónde caímos

Escalando por parámetros no-embedding desde el número de PSRAM:

| | ms/token | fp32 | int4 (est. 0,6×) |
|---|---|---|---|
| **Config S** (v1024 d128 L6, 1,18 M no-emb) | 164,8 | 6,1 tok/s | **~10 tok/s** |
| Config M (v2048 d192 L8, 3,54 M) | 494 | 2,0 tok/s | ~3,4 tok/s |
| Config L (v2048 d256 L8, 6,29 M) | 878 | 1,1 tok/s | ~1,9 tok/s |

Contra las puertas: **Config S es AMARILLO** (5–15 tok/s). Buena para
réplicas cortas y murmullos de reposo; no conversacional. Config M y L son
rojas.

**Pero tres palancas están completamente sin tocar**, y dos son grandes:

1. **`seq_len` es 512 y necesitamos ~64.** Una frase de 15 palabras son ~20
   tokens. Eso recorta la KV cache 8× (676 KB → ~85 KB) *y* recorta el
   cómputo de atención.
2. **El matmul es un triple bucle escalar naíf.** El S3 tiene SIMD de 128
   bits y ESP-DSP trae productos punto optimizados. Para dar escala:
   esp32-ai corre ~17× más parámetros no-embedding a un ritmo de tokens
   similar, lo que implica que su kernel es aproximadamente un orden de
   magnitud mejor que el C de referencia de llama2.c.
3. **int4** — el 0,6× de arriba es una suposición, no una medición.

Así que la lectura honesta **no es "el chip no puede"** — un porteo fp32
naíf y sin vectorizar ya mete a Config S en la banda usable. La pregunta
restante es cuánto trabajo de kernel quiere hacer el lab, y esp32-ai es open
source para aprender de él. *(Posdata: ese trabajo de kernel se hizo — Paso
0.5, rama `spike/tinylm-s3` — y rindió 4,85×.)*

### La pregunta de la contención con la cara, respondida de otro modo

El plan original era medir la inferencia contra una cara ocupada. Ese
planteamiento quedó obsoleto: desde que los ojos van cacheados, la cara solo
renderiza en un parpadeo o cambio de emoción y blitea el resto del tiempo —
está **ociosa la mayor parte del tiempo**. El jitter por token aquí es 31,7
p50 vs 39,2 p99 sin nada más corriendo; el dibujado ocasional de ~8 ms de la
cara más los 23 ms de push no van a perturbar eso de forma significativa. La
preocupación por la contención era un producto del coste del renderer
*antiguo*.

## Riesgos conocidos

- **Contención de ancho de banda de PSRAM.** El framebuffer (112 KB) también
  vive en PSRAM y se manda por DMA a la pantalla cada frame. Las
  activaciones de la inferencia compiten por el mismo bus. Esto puede doler
  más que el tiempo de CPU, y no aparece en un benchmark solo-CPU — que es
  exactamente la razón de la fila 2 de la tabla.
- **El espacio de direcciones de `esp_partition_mmap` es finito.** El S3
  tiene un número limitado de páginas MMU para mapear datos. Un mapeo de
  1 MB va bien; uno de 4 MB puede que no. Conviene saberlo antes de que el
  modelo real crezca.
- **fp32 no es lo que entregaremos.** El Paso 0 se salta la cuantización a
  propósito. Espera que los números int4 difieran; para eso está el factor
  de corrección del Paso 5.

## A dónde lleva esto (no es parte del Paso 0)

Si las puertas pasan: generar ~100k frases etiquetadas por ánimo con Claude
Haiku (~$15), entrenar un tokenizer BPE propio de 1024 tokens sobre ese
corpus, entrenar Config S con el trainer de `nanoGPT` o `llama2.c`,
cuantizar a int4 y entregarlo como la ruta de Brain offline. El corpus ES la
personalidad — y por eso el **formato del corpus, el set de tokens de afecto
y el vocabulario de expresiones son decisiones de grupo**, no algo que se
decida aquí. Ver `docs/ideas-exploration.html`.

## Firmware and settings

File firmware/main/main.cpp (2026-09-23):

// Buddy Zero — the framework seed, wired up. ESP32-S3: a touch wire for
// petting, the GC9A01 round color face, a WS2812 mood ring, and a real Brain.
// Everything talks through the event bus; nothing here calls a driver directly.
//
// Consumes: brain.reply  (the {emotion, utterance} contract, fanned out)
//           speech.say   (routed to face.say until voice subscribes too)
//           brain.thinking · brain.idle  (only on a board with NO reflexes, to
//                          map the brain's mood intent to the built-in moods)
// Emits:    boot.status · boot.ready · face.emotion · face.say · led.mood ·
//           brain.idle   (when a reply sets no mood-bearing expression)
//
// FOUR RULES GOVERN THE ORDER BELOW. Three of them are invisible in the code:
//
//   1. Subscribers before publishers. The bus has no replay — an event
//      published before its subscriber exists is gone, not delivered late.
//   2. The face first, because everything after it is slow. wifi_start alone
//      is up to 25 s, and the splash is what covers it.
//   3. Flash before reflexes: the reflex layer reads /flash.
//   4. Reflexes before senses. Start touch first and the first pet does
//      nothing — the failure a workshop attendee cannot diagnose.
#include "berry_host.h"
#include "brain.h"
#include "bus.h"
#include "expressions.h"
#include "face_model.h"
#include "mood_model.h"
#include "pack.h"
#include "senses.h"
#include "webui.h"

#include "cJSON.h"
#include "driver/gpio.h"
#include "esp_err.h"
#include "esp_littlefs.h"
#include "esp_log.h"
#include "esp_system.h"
#include "freertos/FreeRTOS.h"
#include "freertos/task.h"
#include "nvs_flash.h"
#include "sdkconfig.h"

static const char *TAG = "buddy";

namespace {

// Deliberately NOT ESP_ERROR_CHECK. This now runs before face_start(), so an
// abort here is a black screen and a silent boot loop -- the buddy would have
// no way to say what happened. A missing or corrupt storage partition costs
// the pack, not the creature: without it the built-in face and moods are
// still there, which is the whole point of keeping built-ins.
void mount_flash() {
  esp_vfs_littlefs_conf_t conf = {};
  conf.base_path = "/flash";
  conf.partition_label = "storage";
  conf.format_if_mount_failed = true;
  const esp_err_t err = esp_vfs_littlefs_register(&conf);
  if (err != ESP_OK)
    ESP_LOGE(TAG, "no /flash (%s) — built-in face, no pack and no reflexes",
             esp_err_to_name(err));
}

} // namespace

extern "C" void app_main() {
  // Not ESP_ERROR_CHECK. NO_FREE_PAGES and NEW_VERSION_FOUND are ordinary
  // outcomes after an OTA or a partition-table change, and aborting here is a
  // dark screen and a reboot loop with the reason only on a serial console
  // nobody at a workshop has attached.
  esp_err_t nvs = nvs_flash_init();
  if (nvs == ESP_ERR_NVS_NO_FREE_PAGES ||
      nvs == ESP_ERR_NVS_NEW_VERSION_FOUND) {
    ESP_LOGW(TAG, "nvs needs erasing (%s)", esp_err_to_name(nvs));
    if (nvs_flash_erase() == ESP_OK)
      nvs = nvs_flash_init();
  }
  if (nvs != ESP_OK)
    ESP_LOGE(TAG, "no nvs (%s) — wifi will not start", esp_err_to_name(nvs));

  xTaskCreate(
      [](void *) {
        gpio_config_t io_conf = {};
        io_conf.pin_bit_mask = (1ULL << GPIO_NUM_0);
        io_conf.mode = GPIO_MODE_INPUT;
        io_conf.pull_up_en = GPIO_PULLUP_ENABLE;
        gpio_config(&io_conf);

        int hold_time = 0;
        while (true) {
          if (gpio_get_level(GPIO_NUM_0) == 0) {
            hold_time += 100;
            if (hold_time >= 10000) {
              ESP_LOGW(TAG, "BOOT button held for 10 seconds. Erasing NVS and "
                            "restarting...");
              if (nvs_flash_erase() == ESP_OK) {
                esp_restart();
              } else {
                ESP_LOGE(TAG, "Failed to erase NVS");
                hold_time = 0;
              }
            }
          } else {
            hold_time = 0;
          }
          vTaskDelay(pdMS_TO_TICKS(100));
        }
      },
      "factory_reset", 2048, nullptr, 5, nullptr);

  buddy::bus_start();

#if CONFIG_BUDDY_DEBUG
  // Event tracer: every bus event in the serial log. First subscriber, so it
  // prints before any reflex reacts. Disable via menuconfig → Buddy Zero.
  buddy::bus().subscribe("*", [](const buddy::Event &ev) {
    ESP_LOGI("trace", "[%s] %.120s", ev.name.c_str(), ev.payload.c_str());
  });
#endif

  // Flash and the pack come before the face, and that ordering is not
  // cosmetic. The pack REPLACES the expression and mood tables, and the render
  // task reads those tables every frame — swapping them under a running
  // renderer is a use-after-free, not a style question. Both are fast because
  // the build flashes a prepared LittleFS image; only a board flashed without
  // one pays for a format here.
  mount_flash();
  buddy::pack_load();

  // Now the face, so the boot splash is on screen while everything slower
  // happens behind it. Each step below announces itself on the bus, and the
  // splash shows that as its status line — a real step, not a fake timer.
  buddy::face_start(); // GC9A01 round color face + boot splash
  buddy::led_start();  // WS2812 mood ring

  // Reflex layer: Berry when present, C fallback otherwise.
  buddy::bus().publish("boot.status", "loading reflexes");
  // No C fallback. It was a second copy of the seed behaviour that had
  // already drifted from packs/zero, and its trigger is a build mistake — a
  // clone without --recursive — not a device state. "Never a brick" protects
  // the creature from its environment; it does not owe anyone a quieter,
  // wronger demo that looks like the real one.
  if (!buddy::berry_host_start()) {
    buddy::bus().publish("boot.status", "sin reflejos");
    // No pack reflexes loaded, so nothing would map the brain's mood intent
    // (brain.thinking / brain.idle) to an actual mood. The framework fills in a
    // default mapping to the built-in mood names. A pack with reflexes owns this
    // instead -- packs/zero maps them in reflexes/main.be -- so this fallback
    // exists only for the no-reflexes board.
    buddy::bus().subscribe("brain.thinking", [](const buddy::Event&) {
      // No fallback here: if the pack has no "thinking" mood the spin simply
      // never starts, which is not a stuck state. Falling back to mood 0 would
      // make thinking and idle land on the same mood and erase the indicator.
      buddy::bus().publish("led.mood", "thinking");
    });
    buddy::bus().subscribe("brain.idle", [](const buddy::Event&) {
      // brain.idle MUST end the spin. "calm" is the built-in resting mood, but a
      // pack that replaced the table need not carry it, and on a no-reflexes
      // board nothing else maps brain.idle -- so a missing "calm" would leave
      // the ring spinning. Fall back to mood 0, which always exists (set_moods
      // refuses an empty table) and therefore always resolves.
      const char* rest = "calm";
      if (buddy::mood_index("calm") < 0 && buddy::mood_count() > 0)
        rest = buddy::moods()[0].name.c_str();
      buddy::bus().publish("led.mood", rest);
    });
  }

  // brain.reply is the one contract-level reflex the framework owns:
  // parse {utterance, emotion} and fan out to expressions.
  buddy::bus().subscribe("brain.reply", [](const buddy::Event &ev) {
    // LLMs wrap JSON in fences despite instructions, and describe the format
    // in prose before emitting it. Anchoring on the FIRST '{' broke on
    // "the format {utterance, emotion}: {...}" — an ordinary reply — so every
    // '{' is tried in turn until one parses. cJSON tolerates trailing text.
    const std::string &p = ev.payload;
    cJSON *j = nullptr;
    for (size_t at = p.find('{'); at != std::string::npos && !j;
         at = p.find('{', at + 1))
      j = cJSON_Parse(p.c_str() + at);
    if (!j) {
      ESP_LOGW(TAG, "brain reply has no JSON object: %.200s", p.c_str());
      // No expression was set, so the ring is still on the "thinking" mood the
      // brain signalled at the start of the ask. Signal rest so a reflex (or the
      // firmware default) ends the spin instead of leaving it running.
      buddy::bus().publish("brain.idle");
      return;
    }
    cJSON* emotion = cJSON_GetObjectItem(j, "emotion");
    cJSON* utterance = cJSON_GetObjectItem(j, "utterance");
    // Validated here, not downstream: the registry documents face.emotion as
    // a name from the table, and packs subscribe to the bus. A contract has to
    // hold at the publisher.
    const int ei =
        cJSON_IsString(emotion) ? buddy::emotion_index(emotion->valuestring) : -1;
    if (ei >= 0)
      buddy::bus().publish("face.emotion", emotion->valuestring);
    else if (cJSON_IsString(emotion))
      ESP_LOGW(TAG, "brain returned an unknown emotion: %.32s",
               emotion->valuestring);
    if (cJSON_IsString(utterance)) {
      ESP_LOGI(TAG, "buddy says: %.120s", utterance->valuestring);
      buddy::bus().publish("face.say", utterance->valuestring);
    }
    // What ends the thinking spin is a face.emotion whose expression RESOLVES to
    // a mood: led_ring adopts it, but only calls select_mood for a mood the pack
    // actually defines. An expression with no mood, or one naming a mood this
    // pack dropped, changes nothing on the ring -- so the spin would run on.
    // Signal rest in exactly those cases; a resolvable mood must NOT also get
    // brain.idle, or the resting mood would overwrite the reply's own.
    bool ends_spin = false;
    if (ei >= 0) {
      const buddy::Emotion& e = buddy::emotions()[ei];
      ends_spin = !e.mood.empty() && buddy::mood_index(e.mood.c_str()) >= 0;
    }
    if (!ends_spin) buddy::bus().publish("brain.idle");
    cJSON_Delete(j);
  });

  // speech.say is "these exact words come out", through every channel the
  // buddy has. Today that is the screen; when voice lands, TTS subscribes here
  // too and no reflex changes. face.say stays what it always was — screen
  // only, which is what buddy.hint() publishes.
  buddy::bus().subscribe("speech.say", [](const buddy::Event &ev) {
    buddy::bus().publish("face.say", ev.payload);
  });

  // Senses.
  buddy::bus().publish("boot.status", "waking senses");
  buddy::touch_start(CONFIG_BUDDY_PIN_TOUCH);
#if CONFIG_BUDDY_RC522_ENABLED
  buddy::nfc_start({.sck = CONFIG_BUDDY_RC522_SCK,
                    .miso = CONFIG_BUDDY_RC522_MISO,
                    .mosi = CONFIG_BUDDY_RC522_MOSI,
                    .cs = CONFIG_BUDDY_RC522_CS,
                    .rst = CONFIG_BUDDY_RC522_RST});
#endif

  // Network layer — optional by design ("never brick"). This is the slow part:
  // Up to 25 s: 15 waiting for the association, then 10 more for SNTP. That
  // second one is the common case on guest wifi, where UDP/123 is blocked.
  buddy::bus().publish("boot.status", "conectando wifi");
  const bool online =
      buddy::wifi_start(CONFIG_BUDDY_WIFI_SSID, CONFIG_BUDDY_WIFI_PASS);

  // Outside the branch on purpose: the provisioning portal is FOR the buddy
  // that could not join, so putting its door behind "did we join" made it
  // unreachable exactly when it is needed.
  buddy::webui_start();

  if (online) {
    buddy::bus().publish("boot.status", "waking brain");
    buddy::brain_start({
        .api_key = CONFIG_BUDDY_ANTHROPIC_API_KEY,
        .model = "claude-haiku-4-5",
        .system_prompt =
            "You are Buddy Zero, a tiny cheerful desktop robot made of spare "
            "parts on a breadboard. You are curious, easily delighted, and a "
            "little dramatic. Keep utterances under 20 words.",
    });
  } else {
    buddy::bus().publish("boot.status", "offline");
    // Still start it: with no network it answers every ask with brain.error
    // "no_key"/"offline" instead of swallowing them, so a pack can tell
    // "thinking" from "there is no brain".
    buddy::brain_start({.api_key = "", .model = "", .system_prompt = ""});
  }

  buddy::bus().publish("face.emotion", "neutral");
  // No led.mood here: face.emotion "neutral" makes the ring adopt the neutral
  // expression's own mood (the pack's, or the built-in "calm"), which led_start()
  // already seeded. A hard-coded "calm" would override the pack's choice.
  // Tells the face to glitch out of the splash and become a creature.
  buddy::bus().publish("boot.ready");
  ESP_LOGI(TAG, "buddy zero is alive");
}

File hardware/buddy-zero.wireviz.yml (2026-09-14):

# Buddy Zero wiring (classic ESP32 + GC9A01) — render with:
#   pip install wireviz && wireviz hardware/buddy-zero.wireviz.yml
# Historical: the classic ESP32 was dropped in #80 (no PSRAM, no local model).
# Kept as a record of the Buddy Zero wiring — the pins no longer track
# firmware/main/Kconfig.projbuild, which is esp32s3-only now.

connectors:
  ESP32_DEVKIT_V1:
    type: ESP32 DevKit V1 (30-pin)
    notes: Follow silkscreen labels — clone boards shuffle pin positions
    pinlabels: [3V3, GND, VIN_5V, GPIO4, GPIO5, GPIO18, GPIO21, GPIO23, GPIO25, GPIO26, GPIO27, GPIO13, GPIO14, GPIO15, GPIO32, GPIO34]
  GC9A01:
    type: GC9A01 1.28" round display, 240x240 SPI (3V3 ONLY)
    pinlabels: [VCC, GND, SCL, SDA, RES, DC, CS, BLK]
  WS2812_RING:
    type: WS2812 12-LED ring (5V; brightness capped in firmware)
    pinlabels: [VCC_5V, GND, DIN]
  RC522:
    type: MFRC522 RFID reader (3V3 ONLY, optional — off by default)
    pinlabels: [SDA_CS, SCK, MOSI, MISO, GND, RST, 3V3]
  PETTING_PAD:
    type: bare jumper wire (touch pad, T0)
    pincount: 1

cables:
  W_LCD:
    wirecount: 8
    colors: [RD, BK, YE, OG, WH, GN, VT, GY]
    notes: SPI — short, similar lengths
  W_RING:
    wirecount: 3
    colors: [RD, BK, GN]
    notes: VCC from VIN (5V) — 3V3 is dim and marginal
  W_RC522:
    wirecount: 7
    colors: [VT, VT, VT, VT, BK, WH, RD]
    notes: SPI — MISO on GPIO34 (input-only, boot-safe), NOT the strapping pin 12
  W_TOUCH:
    wirecount: 1
    colors: [WH]

connections:
  -
    - ESP32_DEVKIT_V1: [3V3, GND, GPIO18, GPIO23, GPIO26, GPIO27, GPIO5, GPIO25]
    - W_LCD: [1-8]
    - GC9A01: [VCC, GND, SCL, SDA, RES, DC, CS, BLK]
  -
    - ESP32_DEVKIT_V1: [VIN_5V, GND, GPIO21]
    - W_RING: [1-3]
    - WS2812_RING: [VCC_5V, GND, DIN]
  -
    - ESP32_DEVKIT_V1: [GPIO15, GPIO14, GPIO13, GPIO34, GND, GPIO32, 3V3]
    - W_RC522: [1-7]
    - RC522: [SDA_CS, SCK, MOSI, MISO, GND, RST, 3V3]
  -
    - ESP32_DEVKIT_V1: [GPIO4]
    - W_TOUCH: [1]
    - PETTING_PAD: [1]

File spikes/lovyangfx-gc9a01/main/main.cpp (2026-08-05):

// LovyanGFX spike — test 4: can we have the expressive shapes AND the speed?
//
// Feedback from the lab: A/B's expressiveness is wanted, E's fluidity is
// wanted, the catchlight is not. So the catchlight and rim variants are gone
// and two new approaches are in, both aimed at the same target — B's look at
// E's frame rate.
//
//   A SHIPPED    what round_face.cpp draws today: flat colour + glow. Baseline.
//   B GRADIENT   dithered vertical gradient + glow. The preferred look.
//   C CACHED     pixel-identical to B, but the SDF runs only when the emotion
//                or blink state changes. A saccade is a *translation* of an
//                unchanged image, so it costs a blit, not a re-render.
//   D PRIMITIVE  LovyanGFX shapes only: fillSmoothRoundRect for the eye, then
//                a black triangle to OCCLUDE the brow and a black rect for the
//                squint. Answers "can't we get those shapes another way?" —
//                yes, by subtracting rather than by carving coverage.
#include "lgfx_buddy.h"
#include "logo_hacklab.h"

#include "esp_heap_caps.h"
#include "esp_log.h"
#include "esp_random.h"
#include "esp_timer.h"
#include "freertos/FreeRTOS.h"
#include "freertos/task.h"

#include <cmath>
#include <cstdio>
#include <cstring>
#include <cstdlib>

static const char* TAG = "eyes";
static LGFX_Buddy lcd;
static LGFX_Sprite spr(&lcd);
static uint16_t* fb = nullptr;

// ===== emotion model — copied verbatim from firmware/.../face_model.cpp =====
struct EyeStyle { int width, height, openness, lift, brow; };
struct Emotion { const char* name; EyeStyle eye; int blink_period_ms; uint8_t r, g, b; };

static const Emotion kEmotions[] = {
    {"neutral",    {26, 30, 100, 0,  0},  3800,   0, 190, 255},
    {"happy",      {26, 30, 100, 14, 0},  3000,  40, 235, 120},
    {"curious",    {30, 34, 100, 0,  0},  2600,   0, 210, 235},
    {"sleepy",     {26, 30, 35,  0,  0},  6000,  90,  90, 200},
    {"surprised",  {34, 40, 100, 0,  0},  5000, 150, 240, 255},
    {"angry",      {28, 28, 100, 0,  1},  3200, 255,  50,  25},
    {"sad",        {24, 26, 75,  0, -1},  5200,  50, 110, 255},
    {"suspicious", {26, 30, 55,  0,  1},  2200, 255, 180,  20},
};
static const int kEmotionCount = sizeof(kEmotions) / sizeof(kEmotions[0]);

constexpr int W = 240, H = 240;
constexpr float S = 2.6f;
constexpr int CX = 120, CY = 120, GAP = 42;

// All three are now cached or cheap, so they run at comparable speed and the
// only thing that differs is the LOOK. That is the comparison the lab asked
// for: with caching, the expensive renderer costs nothing at runtime, so the
// choice between flat and gradient is purely aesthetic.
enum Variant { V_FLAT = 0, V_GRAD, V_PRIM, V_COUNT };
static const char* kVariantName[] = {"A FLAT cached", "C GRAD cached", "D PRIMITIVE"};

// The three openness levels a blink passes through. Cached variants
// pre-render these, so a blink costs three blits instead of three renders.
// How deep the angled upper lid cuts, as a fraction of eye height. Was 0.5,
// which removed half the eye and produced wedges instead of angry eyes.
constexpr float kBrowDepth = 0.24f;

static const int kLevels[] = {100, 45, 12};
static const int kLevelCount = 3;

inline float clampf(float v, float a, float b) { return v < a ? a : (v > b ? b : v); }

constexpr uint16_t rgb(int r, int g, int b) {
  return static_cast<uint16_t>(((r & 0xF8) << 8) | ((g & 0xFC) << 3) | (b >> 3));
}

// LovyanGFX stores 16bpp sprites BIG-endian (SPI byte order). Confirmed on
// hardware by the panel test card. Convert only at the buffer boundary.
inline uint16_t to_store(uint16_t native) { return __builtin_bswap16(native); }
inline uint16_t from_store(uint16_t stored) { return __builtin_bswap16(stored); }

static const uint8_t kBayer[16] = {0, 8, 2, 10, 12, 4, 14, 6, 3, 11, 1, 9, 15, 7, 13, 5};
inline uint16_t rgb_dither(int x, int y, float rf, float gf, float bf) {
  const float t = (kBayer[((y & 3) << 2) | (x & 3)] - 7.5f) / 15.0f;
  const int r = static_cast<int>(clampf(rf + t * 12.0f, 0.f, 255.f));
  const int g = static_cast<int>(clampf(gf + t * 6.0f, 0.f, 255.f));
  const int b = static_cast<int>(clampf(bf + t * 12.0f, 0.f, 255.f));
  return rgb(r, g, b);
}

inline uint16_t blend565(uint16_t bg, uint16_t fg, float a) {
  const int br = (bg >> 11) & 0x1F, bgg = (bg >> 5) & 0x3F, bb = bg & 0x1F;
  const int fr = (fg >> 11) & 0x1F, fgg = (fg >> 5) & 0x3F, fbb = fg & 0x1F;
  const int r = br + static_cast<int>((fr - br) * a + 0.5f);
  const int g = bgg + static_cast<int>((fgg - bgg) * a + 0.5f);
  const int b = bb + static_cast<int>((fbb - bb) * a + 0.5f);
  return static_cast<uint16_t>((r << 11) | (g << 5) | b);
}
inline void blend_at(int x, int y, uint16_t c, float a) {
  if (x < 0 || x >= W || y < 0 || y >= H || a <= 0.f) return;
  uint16_t& p = fb[y * W + x];
  p = to_store(blend565(from_store(p), c, a > 1.f ? 1.f : a));
}
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

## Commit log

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2026-07-23 Fix ESP32-S3 bring-up: touch polarity, task stack, TLS
    Hardware/reliability fixes found while bringing the S3 up:
    - Touch reads inverted on the S3 (hw v2 raises the reading, classic lowers);
    branch the threshold on SOC_TOUCH_SENSOR_VERSION.
    - app_main overflowed its 3584-byte stack bringing up esp_lcd + Berry; raise
    to 8192. Enable the BOYA flash chip driver (Hosyond clones).
    - Brain adapter: reuse the TLS connection across requests (the classic-ESP32
    software-ECC handshake is 3-6 s and tripped the watchdog); tighten the
    prompt to spoken words only, no asterisk stage directions.
    - Document these gotchas and add the round-display face mask.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
    [buddy-round-mask-no-base.3mf, buddy-round-mask.stl]
2026-07-23 Add color face renderer and WS2812 mood ring
    Overhaul the expression system on the round display:
    - Anti-aliased SDF eye renderer (smooth lozenges, glow halo, slanted brows),
    solid color to avoid RGB565 gradient banding, and the horizontal-mirror fix.
    - Move the mood color into the shared face_model so the eyes and ring always
    match; give each emotion a distinct color.
    - New WS2812 ring backend (led_strip): the ring glows the emotion color and
    animates per led.mood (breathe / comet / off). Mood indicator is a
    menuconfig backend choice (ring default, single PWM LED for the PoC).
    - Replace the 3x5 text font with a legible 5x7 font; fix a draw_text buffer
    overrun that rebooted on long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
    [main.cpp, round_face.cpp]
2026-08-04 Add 2D gaze to the face (face.look)
    The eyes could already drift horizontally during idle saccades; this makes
    gaze a first-class, addressable thing. face.look "x,y" (each -100..100)
    points both eyes at a spot on the screen, easing toward the target and
    holding it for 1.5 s before the buddy drifts back to its own idle behavior.
    Deliberately decoupled from any particular input: a Sense, a reflex, or a
    future sprite can all drive it. That is why the target expires — the buddy
    should always return to being itself when nothing is asking for its
    attention.
    [round_face.cpp]
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2026-08-04 Add LovyanGFX spike: gate passed on ESP-IDF v6.0.2
    Runs on a second S3 + GC9A01 rig so the working PoC never gets taken apart.
    The gate was whether LovyanGFX builds against v6.0.2 at all — v6 removed the
    legacy driver APIs that forced our own rewrite, and LovyanGFX reaches deep
    into the SPI/LCD peripherals. It builds clean, costs 37,642 B of flash (I had
    guessed 100-200 KB), and the panel came up with correct colours and correct
    orientation with no configuration fight — retiring the risk that swapping
    panel drivers means re-deriving the mirror and colour-order fixes we bled for.
    The measurement that matters: a full-frame push takes 24.01 ms against 23.04 ms
    of theoretical SPI wire time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
    [lgfx_buddy.h, main.cpp]
2026-08-05 Eye showcase + renderer optimisation: 33% faster, gradient bug fixed
    Renders the same emotion five ways so the lab can pick the eye look rather
    than have one handed down: as-shipped, dithered gradient, catchlight, depth,
    and LovyanGFX's own primitive for contrast.
    Corrects an earlier claim in this file. The fillScreen benchmark said we were
    wire-bound, but fillScreen is a memset and never touches the eye maths. With
    the real renderer the SDF drawing costs 1.3-4.4x the wire time — we are
    decisively CPU-bound, and that is very likely why the face has felt sluggish.
    Five inner-loop changes (-O2 for this component, skip the sqrtf outside the
    rounded corners, hoist the per-row and per-eye ter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
    [main.cpp]
2026-08-05 Fix byte order: LovyanGFX sprites are big-endian
    The eyes rendered as horizontal rainbow stripes on the panel while decoding
    perfectly on the laptop. Both were true: LovyanGFX stores 16bpp sprites
    big-endian for the SPI bus, we wrote native little-endian into getBuffer(),
    and the screenshots were decoded with the same wrong assumption used to write
    them — so they agreed with themselves and proved nothing.
    Photographs of the panel caught it. A flat colour byte-swaps to a solid wrong
    colour; a gradient byte-swaps to rainbow banding, because the low byte holding
    blue becomes red and cycles down the ramp. Both appeared exactly as predicted.
    Proved with a test card drawing three colours three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
    [main.cpp]
2026-08-05 Cached eye rendering: B's exact pixels at 32 fps, up from 13
    The lab pushed back on my claim that LovyanGFX primitives could not produce
    the brow slant, and on having to choose between expressiveness and fluidity.
    Both objections were correct.
    C CACHED renders the SDF only when the emotion or blink state changes and
    blits otherwise, because a saccade is a translation of an unchanged image.
    Pixel-identical to B, 13.0 -> 32.1 fps, at the cost of 3 x 115 KB of PSRAM and
    a ~110 ms rebuild per emotion change.
    D PRIMITIVE gets the brow slant from library primitives after all: draw the
    whole eye, then occlude with a black triangle — subtraction instead of coverage
    multiplication. 39.4 fps, lose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
    [main.cpp]
2026-08-05 Add intruder demo: sprite bothers the eyes, eyes track it
    Demonstrates that our own eye renderer and LovyanGFX sprites share one canvas:
    the SDF writes pixels into the main sprite's buffer, LovyanGFX draws into the
    same buffer, and other sprites composite on top with transparency — one push
    to the panel at the end.
    A placeholder sprite wanders the screen; the eyes follow it using the same
    gaze offset as the firmware's face.look, and the buddy flinches when it comes
    too close. 27.3 fps with tracking and compositing, against 32.1 for cached
    eyes alone — the sprite costs about 5 fps.
    The placeholder is a drop-in for the real HackLab logo, which will become an
    RGB565 + 8-bit alpha array co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
    [main.cpp]
2026-08-05 Add HackLab logo, fix the brow geometry, restructure the demo
    The logo comes from the project SVG via rsvg-convert at 256px, cropped to
    content and resized to 60px, stored as native RGB565 plus a separate 8-bit
    alpha channel (10.8 KB). It is composited through our own blend rather than a
    transparent-colour key, so the circle's edge stays soft instead of aliased.
    The brow fix is one number. browAmt sets how far the angled upper lid cuts
    down at its deep end, as a fraction of eye height. It was 0.5 — half the eye —
    so what survived was a wedge, not an eye with a tilted lid. At 0.24 it reads
    as an eyelid. This is why angry, sad and suspicious have looked broken since
    the first PoC; the mir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
    [main.cpp]
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2026-08-05 Add the full eye-variant contact sheet (8 emotions x 3 techniques)
    Clean stills — no logo, no gaze offset — so the sheet compares the eye
    rendering and nothing else. All 24 dumps checksum-verified.
    The sheet immediately surfaces a bug the single-emotion shots hid: the glow
    halo is computed from the uncut lozenge, so it ignores the brow slant and the
    happy squint. On happy it is glaring — the squint removes the lower half of
    the eye, but the glow still fills that region with dark green, so the eye
    reads as a half-lit block instead of a squint. D PRIMITIVE looks cleaner there
    purely because it has no glow at all.
    Also visible: on surprised the two eyes overlap by a few pixels and merge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
    [main.cpp]
2026-08-05 Fix glow ignoring the lid cut, and keep the seam on overlapping eyes
    The lid cut multiplied only ecov, so the glow halo was still computed from the
    uncut lozenge and filled the region the lid had removed. On happy the squint
    takes the lower half of the eye, but the halo painted it dark green, so it
    read as a half-lit block rather than a squint. The cut factor is now computed
    once and applied to both the eye body and the glow — a lid that covers the eye
    covers its glow too. Also visibly cleans up angry, sad and suspicious.
    D PRIMITIVE now draws a 2 px black rim before each eye. It is invisible against
    the black background, but where the eyes overlap on surprised it preserves the
    seam so th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
    [main.cpp]
2026-08-05 Make happy actually blink, and close the lid downward
    Happy did not blink, it vanished. The squint was an absolute offset that did
    not scale with openness: at 45% the eye is 35 px tall but the lower lid still
    sat 36 px up from the bottom, so the lid landed above the eye's top edge and
    removed all of it. The demo's flinch also draws at 45%, which is where the
    extra hide/show came from. The squint now scales with how open the eye is.
    Blinks also now close downward — the lower lid stays put and the upper lid
    comes down to meet it. Shrinking about the centre reads as a squash, not a
    blink. The blink sequence reopens through the mid level (45, 12, 45) so it is
    symmetric rather than snapping ba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
    [main.cpp]
2026-08-05 Add glitched boot splash with the HackLab logo
    Keeping the backlight off through panel init means the uninitialised panel is
    never seen: the boot reads as dark -> static -> logo rather than noise -> logo.
    First frame lands 828 ms after reset (panel init itself is 749 ms of that, and
    is a hard floor — GC9A01 reset and sleep-out delays).
    The splash tunes in like a bad signal finding lock, over ~1.6 s at 16.5 fps.
    Five effects applied to the framebuffer after the logo is drawn clean, in the
    order a real bad signal applies them: scanlines, band tearing, chroma split,
    a rolling bar, and snow, all scaled by a decaying damage factor. Because it is
    a post-process it composes with anything — it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
    [main.cpp]
2026-08-05 Move the face to LovyanGFX with cached eyes and a glitched boot splash
    Ports what the spike settled into the real firmware. The arrangement is two
    layers: the EYES stay ours, because the brow slant and the happy squint are
    carved out of the shape as coverage and no library primitive can express that;
    everything else — panel driver, sprites, fonts, blitting — is LovyanGFX, added
    as a submodule alongside Berry since it is not on the component registry.
    The eyes are cached. The SDF costs 40-100 ms a frame but the image only changes
    on a blink or an emotion change, so a saccade is a translation of an unchanged
    image. Three PSRAM sprites per emotion, blitted at a gaze offset: 13 fps -> ~30,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
    [lgfx_buddy.h, main.cpp, round_face.cpp]
2026-08-06 Fix the RC522 pin defaults, which were dangerous on the S3
    The defaults were the classic-ESP32 PoC values hardcoded in main.cpp, and two
    of them — GPIO 19 and 23 — are the S3's USB pins. Anyone enabling the reader
    would have fought that before suspecting the pin map.
    Moves them into menuconfig like every other pin, on SPI3 so the reader does not
    share a bus with the display, with defaults chosen to avoid all of the S3's
    landmines: the display bus (7-12), USB (19/20), flash (26-32), octal PSRAM
    (33-37), strapping (0/3/45/46), touch (4) and the LED ring (21).
    Both the enabled and disabled build paths compile. Still untested against real
    hardware, and the help text says so.
    Co-Authored-B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
    [main.cpp]
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2026-08-08 Bring back the classic ESP32 — colour face, rendered in bands
    Reverses 0392e91, but not by restoring the mono OLED backend. The classic
    DevKit V1 now runs the SAME colour face as the S3.
    What made that possible: the 460 KB of PSRAM the face appears to need is
    the eye-level sprite CACHE, not the rendering. Drawing needs one frame
    buffer, and a frame can be built in horizontal bands. So kBandH is H on
    the S3 (a single band - byte-identical to the old path, since banding
    must not be able to regress the target that already works) and 48 on
    classic, where a band is 23 KB instead of 115 KB. That matters because a
    WROOM-32's largest contiguous DRAM block is only ~110-120 KB, about one
    full frame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
    [partitions_4mb.csv]
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2026-08-08 Repo entry points for the whole team, Spanish-first
    Written directly in Spanish (the agreed final state for docs) so nothing
    gets translated twice. New: CONTRIBUTING.md, docs/README.md index, and
    short READMEs for packs/, spikes/ and hardware/. Rewritten: the root
    README as a real entry point (what it is, 5-minute start with the
    --recursive trap called out, which board gives you what, where each team
    starts, repo map), and firmware/README.md for the two targets with the
    per-chip wiring table.
    hardware/buddy-zero-wiring.md was documenting the dead SSD1306 build -
    worse, its RC522 pins are now the display's pins on classic. Rewritten
    for classic + GC9A01 with the new per-target defaults, the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
    [buddy-zero.wireviz.yml]
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2026-08-09 Band-clip the draw scan: classic ESP32 4.0 -> 14.4 fps, and add CI
    Measuring the wired classic board exposed a real bug in the banded
    renderer. draw_eye and draw_logo clipped their WRITES to the current band
    but still scanned the full shape, so the per-pixel SDF maths ran once per
    band and 4/5 of it was computed and thrown away. Clipping the scan itself
    takes a frame from 251 ms to 69 ms - 4.0 fps to 14.4 - with identical
    output. The S3 is untouched in behaviour (single band) and gains a little
    by no longer iterating the glow margin off-screen.
    The docs estimated ~13 fps, inherited from the S3's pre-cache number. It
    happened to land near the FIXED figure, which is exactly why nobody
    questio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
    [round_face.cpp]
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2026-08-12 Read what the sticker says, not just who it is
    Cartridges keyed on UID do not work: you have to edit every pack with every
    UID, and nothing is shareable. Worse, they did not work at all for the tags
    Daniel is actually using -- the driver did cascade level 1 only and reported
    the cascade tag 0x88 plus three bytes as if it were a UID, so every 7-byte
    NTAG came out wrong. Its own header comment had said "fix in v1" since the
    PoC. This is v1.
    Three events, all plain strings, no schema:
    nfc.tag UID hex every presentation (now correct for 4 and 7 bytes)
    nfc.text decoded NDEF only when the tag carries readable content
    nfc.gone empty the tag left the field
    nfc.gone is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
    [rc522.cpp]
2026-08-12 Give the buddy a font that can spell "mañana"
    Accented characters drew as boxes. Not an encoding bug -- LovyanGFX decodes
    UTF-8 unconditionally and got U+00E1 correctly. The font simply had no such
    glyph: lgfx_fonts.cpp:217 is `(uniCode - 0x20) < 0x60`, so Font2 is exactly
    96 glyphs, printable ASCII. Every other font the library ships stops at 0x7E
    too, and its only Unicode fonts are efont -- 17 to 32 MB of CJK source.
    So tools/make_font.py generates font_latin.h: DejaVu Sans 13px, codepoints
    0x20-0xFF, contiguous because GFXfont::getGlyph indexes glyph[c - first] with
    uint16_t bounds. 1376 B of bitmap plus a 2688 B table, and nm confirms the
    linker then dropped Font2's tables entirely, so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
    [round_face.cpp]
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2026-09-02 senses: three reviews, and the bug from Saturday
    Adversarial, architecture and secrets reviews on the component as it stood.
    Boot no longer aborts. Seven ESP_ERROR_CHECK calls ran on the main task, so a
    loose RC522 wire took the whole buddy down — which is what happened in the
    session on the 30th, and cost the afternoon until someone found the cable.
    touch_start() and nfc_start() now return bool and log. VersionReg is checked
    too: without it, a missing reader polls a dead bus forever in silence.
    Classic ESP32: channel_for_gpio assumed the S3's identity mapping. On that
    part the default CONFIG_BUDDY_PIN_TOUCH of 4 selected T4 = GPIO13, which is
    also the default RC522 MOSI, so the petting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
    [main.cpp, rc522.cpp, touch_sense.cpp]
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2026-09-03 brain: four reviews
    Adversarial, performance, architecture and secrets on the component as it
    stood.
    The response body was accumulated with no ceiling. Exceptions are off, so a
    failed allocation is abort(), and a chunked response that never ends reaches
    it — the 30 s timeout is per read and every chunk resets it. On the classic
    board, with no PSRAM to absorb it, a few hundred KB is enough: a proxy error
    page will do. Capped at 32 KB.
    cJSON was allowed 1000 levels of nesting and costs ~96 bytes of stack per
    level. The bus task has 6144 and runs the second parse inline, so 64 levels
    walks off the end of it; the brain task has 10240 and runs the first. The
    stack canary is only inspected at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
    [main.cpp]
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2026-09-03 bus + main: three reviews
    Adversarial, performance and architecture on the component every other one
    hangs off.
    The expensive thing on the bus task is not the bus. CONFIG_BUDDY_DEBUG is
    default y, its tracer is subscribed first and logs from inside the dispatch
    loop, and the UART console busy-waits on the TX FIFO: 87 us per character at
    115200, so 3.5 ms for a short event line and 13 ms for a brain reply. One pet
    gesture publishes four events and blocks the bus for 15-20 ms, ahead of the
    face and the LEDs. Everything else in this component costs microseconds. Now
    default n, with the arithmetic in the help text.
    nvs_flash_init was ESP_ERROR_CHECK on the first line of app_main. NO_FREE_PAGES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
    [main.cpp]
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2026-09-03 Move expressions and moods out of C++ and into the pack
    Closes the half of #19 that firmware owns, migrates kEmotions (#18),
    implements pack-defined moods (#44), and makes packs/zero a real pack
    rather than a directory of intentions.
    kEmotions and the four hard-coded led.mood values were both closed
    vocabularies compiled into the binary, which made a group decision one
    person's call. Both are now runtime tables loaded from the pack, with
    the old contents kept as the fallback -- a board with no pack, or with
    a pack that fails to parse, behaves exactly as it did.
    Moods get five fixed animation primitives (solid, breathe, spin, pulse,
    off) with expressiveness in the parameters. Pulse is a fas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
    [main.cpp]
2026-09-03 Keep the schema in English, and the Spanish neutral
    Three corrections from review.
    "registro" as a schema key broke a rule CONTRIBUTING already states --
    code and code comments are English -- and produced exactly the mix that
    reads badly: "registro" sitting next to "colors" and "anim". The key is
    now `register` (the C++ field is `register_`, since register is a
    reserved word). Docs keep saying "registro" in prose, because docs are
    Spanish; only the key is code.
    That boundary was never written down, so it is now: in a pack, the KEY
    is code and the VALUE is content. Keys are English like event names;
    values are written by whoever authors the pack, in the language its
    pack.json declares.
    "br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
    [test_pack.cpp]
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2026-09-03 Make the pack loader survive a hostile pack
    Three reviews -- adversarial, performance and architecture -- on the branch as
    it stood. The performance one came back clean and corrected two of my own
    claims, so this is the other two.
    The one that would have hurt: a 200-byte pack.json bricks the board. cJSON's
    parser is recursive at ~96 bytes of stack per level, measured against the
    vendored copy, and the main task has 8192 -- so ~85 levels of nesting panics
    inside cJSON, before face_start(), from a file that survives the reboot. The
    64 KB size cap protects nothing against 200 brackets. Depth is now counted
    before the document reaches the parser.
    Non-finite numbers inverted every clamp. 1e999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
    [main.cpp]
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2026-09-05 face: claim SPI2 before LovyanGFX does, or IDF 6.1 panics on boot
    LovyanGFX fills spi_bus_config_t with 0xFF and then writes back only the
    fields it knows about. Every int it leaves alone becomes -1, which is the
    correct "unused" sentinel for a pin — which is why this was harmless for
    years. ESP-IDF 6.1 added dma_burst_size to that struct, and that one is not
    a pin. GDMA is handed 0xFFFFFFFF, rejects it as not a power of two:
    gdma: gdma_config_transfer(425): invalid max_data_burst_size: 4294967295
    spi_common: alloc_dma_chan(319): config gdma tx transfer failed
    spi_bus_initialize() then panics on the way out of its own cleanup, which
    frees a DMA context it never allocated (LoadProhibi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
    [lgfx_buddy.h, round_face.cpp]
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2026-09-08 expressions: survive losing the eye cache, and finish the classic cleanup
    Answers the Copilot review on this PR, plus the adversarial and performance
    reviews run on the result.
    The critical one. Dropping the banded renderer removed the only path that
    could draw without the PSRAM cache, and face_start() still treated a failed
    cache allocation as a log line: it carried on, and build_cache() then
    memcpy'd 115,200 bytes into a null buffer on the first frame. Copilot's
    suggestion was to stop face startup; a buddy with no face is worse than a
    slow one, so the renderer degrades instead. All three cache sprites or none,
    because a partial cache would make every draw ask which levels survived, and
    th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
    [round_face.cpp]
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2026-09-11 fix: address security and stability issues in captive portal (PR #81)
    This commit resolves all 12 feedback points raised during the review
    of the captive portal implementation, focusing on security boundaries,
    memory safety, and event contract compliance.
    Security & Provisioning:
    - webui: Restrict both GET and POST to `/setup` strictly to AP mode to
    prevent unauthenticated credential overwriting from the LAN.
    - webui: Replace hardcoded 'buddy123' AP password with a truly random
    passphrase (`esp_random()`) generated per provisioning session.
    - webui/expressions: Adhere to the `config.setup` event contract by
    publishing only the SSID to the event bus. The display component
    securely fe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
    [main.cpp, round_face.cpp]
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2026-09-12 face: answer the review notes on the neutral-boot change
    Follow-up to 9b6c672, from the three reviews of that commit.
    Architecture: the slot-0 guarantee was implicit. Document it from both sides --
    face_model.h now states set_emotions() moves "neutral" to slot 0, and
    round_face.cpp:86 names set_emotions() as why its s_emotion == 0 start is safe.
    Turns a latent coupling (weaken the swap and the eyes silently boot wrong, with
    no failing assertion) into a documented one.
    Adversarial and performance both noted the ring seed ran after the two
    subscribe() calls, leaving a theoretical window for a face.emotion handler to
    race the seed writes. Not triggerable today (no face.emotion before the netw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
    [round_face.cpp]
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2026-09-13 brain: signal thinking/idle as intent, let the pack pick the mood
    Finding #8 from the #45 last review (Copilot, 12-sep). Daniel's call:
    reflex-native indirection.
    The brain published led.mood "thinking"/"calm" by hard-coded name. A pack that
    replaced the mood table without those two turned the brain's thinking and reset
    signals into unknown-mood no-ops (select_mood keeps the current mood and warns).
    Now the brain publishes intent, not a mood name:
    - brain.thinking when an ask starts (was led.mood "thinking").
    - brain.idle when it ends WITHOUT an expression to carry the mood: an error
    (finish()), a reply with no usable emotion, or a reply that is not JSON
    (main.cpp). A reply WITH an emo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
    [main.cpp]
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
